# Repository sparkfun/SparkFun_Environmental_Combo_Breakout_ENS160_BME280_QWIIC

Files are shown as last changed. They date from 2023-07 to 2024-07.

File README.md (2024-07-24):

SparkFun Environmental Combo Breakout - ENS160/BME280 (Qwiic)
========================================

SparkFun Environmental Combo Breakout - ENS160/BME280 (Qwiic) (https://www.sparkfun.com/products/22858)

[*SparkFun Environmental Combo Breakout - ENS160/BME280 (Qwiic) (SEN-22858)*](https://www.sparkfun.com/products/22858)

Environmental sensor that includes the ENS160 and BME280.

Repository Contents
-------------------

* **/Documentation** - Data sheets, additional product information
* **/Hardware** - Eagle design files (.brd, .sch)
  * **/Production** - Production panel files (.brd)

Documentation
--------------
* **[ENS160 Library](https://github.com/sparkfun/SparkFun_Indoor_Air_Quality_Sensor-ENS160_Arduino_Library)** - Arduino library for the ENS160
* **[BME280 Library](https://github.com/sparkfun/SparkFun_BME280_Arduino_Library)** - Arduino library for the BME280
* **[Fritzing Part](https://github.com/sparkfun/Fritzing_Parts/blob/main/products/22858_sfe_qwiic_environmental_combo_ens160_bme280.fzpz)** - Fritzing Part for the Environmental Combo Breakout - ENS160/BME280.
* **[Hookup Guide](http://docs.sparkfun.com/SparkFun_Environmental_Combo_Breakout_ENS160_BME280_QWIIC/)** - Basic hookup guide for the Environmental Combo Breakout - ENS160/BME280.

Product Versions
----------------
* [SEN-22858](https://www.sparkfun.com/products/22858) - v1.1

Version History
---------------
* v1.0 - Initial Release

License Information
-------------------

This product is _**open source**_!

Please review the LICENSE.md file for license information.

If you have any questions or concerns on licensing, please contact technical support on our [SparkFun forums](https://forum.sparkfun.com/viewforum.php?f=152).

Distributed as-is; no warranty is given.

- Your friends at SparkFun.

_<COLLABORATION CREDIT>_

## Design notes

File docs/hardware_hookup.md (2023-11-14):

### Connecting via Qwiic

Connecting to the Qwiic Environmental Combo Breakout - ENS160/BME280 is simple. You will just need a microcontroller and a Qwiic cable. In this case, we used an ATmega328P as the microcontroller (we specifically tested the Arduino Libraries with the SparkFun RedBoard Qwiic). Insert one end of the Qwiic cable into the Qwiic Environmental Combo Breakout's Qwiic connector and the other end of the cable to your microcontroller's Qwiic connector. Then insert a USB cable into the RedBoard Qwiic to power and program.

<div style="text-align: center;">
  <table>
    <tr style="vertical-align:middle;">
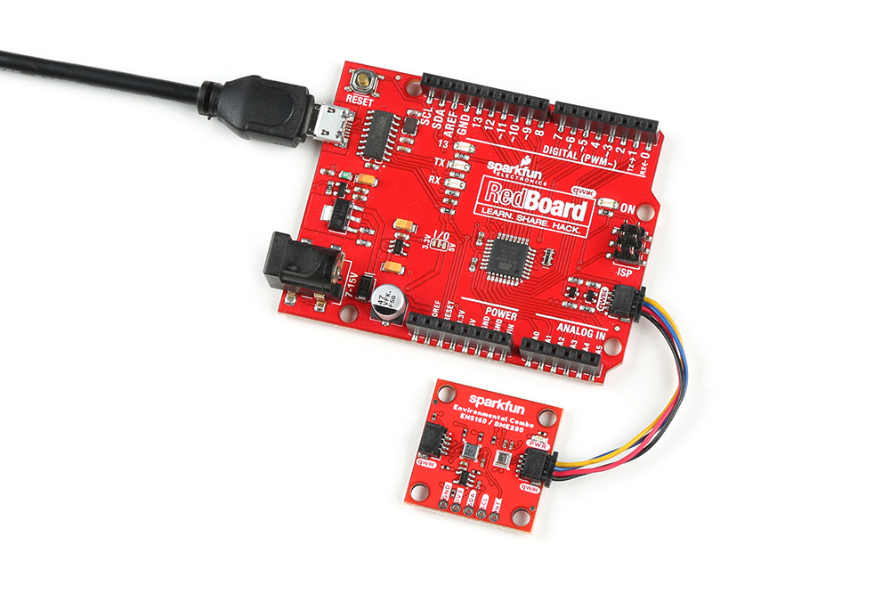
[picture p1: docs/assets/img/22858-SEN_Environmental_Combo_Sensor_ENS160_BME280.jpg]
Basic Hookup with RedBoard Qwiic, Qwiic cable, and Qwiic Environmental Combo Breakout - ENS160/BME280
     <td style="text-align: center; vertical-align: middle;"></td>
    </tr>
  </table>
</div>

### Connecting via PTH I<sup>2</sup>C and Interrupt Pins

!!! note
    For temporary connections to the PTHs, you could use IC hooks to test out the pins. However, you'll need to solder headers or wires of your choice to the board for a secure connection. You can choose between a combination of [header pins and jumper wires](https://learn.sparkfun.com/tutorials/how-to-solder-through-hole-soldering/all), or [stripping wire and soldering the wire](https://learn.sparkfun.com/tutorials/working-with-wire/all) directly to the board.

    <div class="grid cards col-4" markdown>

    -   <a href="https://learn.sparkfun.com/tutorials/how-to-solder-through-hole-soldering/all">
          <figure markdown>
            How to Solder: Through Hole Soldering
          </figure>
        </a>

        ---

        <a href="https://learn.sparkfun.com/tutorials/how-to-solder-through-hole-soldering/all">
          <b>How to Solder: Through Hole Soldering</b>
        </a>
    <!-- ----------WHITE SPACE BETWEEN GRID CARDS---------- -->

    -   <a href="https://learn.sparkfun.com/tutorials/working-with-wire/all">
          <figure markdown>
            Working with Wire
          </figure>
        </a>

        ---

        <a href="https://learn.sparkfun.com/tutorials/working-with-wire/all">
          <b>Working with Wire</b>
        </a>
    <!-- ----------WHITE SPACE BETWEEN GRID CARDS---------- -->
    </div>

For users that are connecting to the PTH I<sup>2</sup>C and interrupt pins on the edge of the board, you will need to connect the RedBoard Qwiic and sensor like the table listed below. For users that are connecting to a different microcontroller, make sure to connect to its respective pins for the I<sup>2</sup>C and interrupt pins as they may be defined differently.

<div style="text-align: center;">
    <table>
        <tr>
            <th style="text-align: center; border: solid 1px #cccccc;">RedBoard Qwiic
            <br />(I/O set to 3.3V!)
            </th>
            <th style="text-align: center; border: solid 1px #cccccc;">Environmental Combo Breakout <br />ENS160/BME280 (Qwiic)
            </th>
        </tr>
        <tr>
            <td style="text-align: center; border: solid 1px #cccccc;" bgcolor="#f2dede"><font color="#000000">3.3V</font>
            </td>
            <td style="text-align: center; border: solid 1px #cccccc;" bgcolor="#f2dede"><font color="#000000">3.3V</font>
            </td>
        </tr>
        <tr>
            <td style="text-align: center; border: solid 1px #cccccc;" bgcolor="#DDDDDD"><font color="#000000">GND</font>
            </td>
            <td style="text-align: center; border: solid 1px #cccccc;" bgcolor="#DDDDDD"><font color="#000000">GND</font>
            </td>
        </tr>
        <tr>
            <td style="text-align: center; border: solid 1px #cccccc;" bgcolor="#fff3cd"><font color="#000000">SCL (A5)</font>
            </td>
            <td style="text-align: center; border: solid 1px #cccccc;" bgcolor="#fff3cd"><font color="#000000">SCL</font>
            </td>
        </tr>
        <tr>
            <td style="text-align: center; border: solid 1px #cccccc;" bgcolor="#cce5ff"><font color="#000000">SDA (A4)</font>
            </td>
            <td style="text-align: center; border: solid 1px #cccccc;" bgcolor="#cce5ff"><font color="#000000">SDA</font>
            </td>
        </tr>    
        <tr>
            <td style="text-align: center; border: solid 1px #cccccc;" bgcolor="#cce5ff"><font color="#000000">2</font>
            </td>
            <td style="text-align: center; border: solid 1px #cccccc;" bgcolor="#cce5ff"><font color="#000000">INT</font>
            </td>
        </tr>
    </table>
</div>

Note that you will also need to also make sure that the logic levels are matched to 3.3V if you are not connecting the Qwiic connector (this connector has built-in logic level circuits on the I<up>2</sup>C data and clock lines). The default for the RedBoard Qwiic is set to 5V so you will need to cut the trace and add a solder blob between the center pad and the pad close to the 3.3V label.

<div style="text-align: center;">
  <table>
    <tr style="vertical-align:middle;">
     <td style="text-align: center; vertical-align: middle;"><a href="https://cdn.sparkfun.com/assets/learn_tutorials/8/4/4/Qwiic_Redboard_-_IO_Jumper.JPG">RedBoard Qwiic I/O Jumper Highlighted</a></td>
    </tr>
  </table>
</div>

!!! note
    For users using the [RedBoard Plus](https://www.sparkfun.com/products/18158), there is a I/O switch available as opposed to an I/O jumper. You could flip the switch toward the 3.3V side to set the logic level as well.
    <div style="text-align: center;">
      <table>
        <tr style="vertical-align:middle;">
         <td style="text-align: center; vertical-align: middle;"><a href="https://cdn.sparkfun.com/assets/learn_tutorials/1/7/5/8/18158-SparkFun_RedBoard_Plus_IO_Logic_Switch.jpg">RedBoard Plus I/O Switch Highlighted</a></td>
        </tr>
      </table>
    </div>

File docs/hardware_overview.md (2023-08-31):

The Environmental Combo Board breaks out the I<sup>2</sup>C port for the ENS160 and the BME280. The ScioSense's ENS160 is populated on the left side below the label ENS160. The independent hotplate control allows the detection of volatile organic compounds (VOCs) including ethanol, toluene, hydrogen and oxidizing gases with superior sensitivity. The ENS160 supports intelligent algorithms to process raw sensor measurements on-chip. These algorithms calculate <a href="../assets/component_documentation/ENS160-White-Paper.pdf">CO<sup>2</sup>-equivalents, TVOC, air quality indices (AQIs)</a> and perform humidity and temperature compensation, as well as baseline management, all on chip. Raw sensor measurements can be read for further customization. Bosch's BME280 is populated on the right side below the label BME280. The BME280 measures three different atmospheric properties: [ambient temperature](https://en.wikipedia.org/wiki/Atmospheric_temperature), [relative humidity](https://en.wikipedia.org/wiki/Relative_humidity), and [barometric pressure](https://en.wikipedia.org/wiki/Atmospheric_pressure). The BME280 can also calculate altitude changes, or absolute altitude if the locally reported barometric pressure is known.

<div style="text-align: center;">
  <table>
    <tr style="vertical-align:middle;">
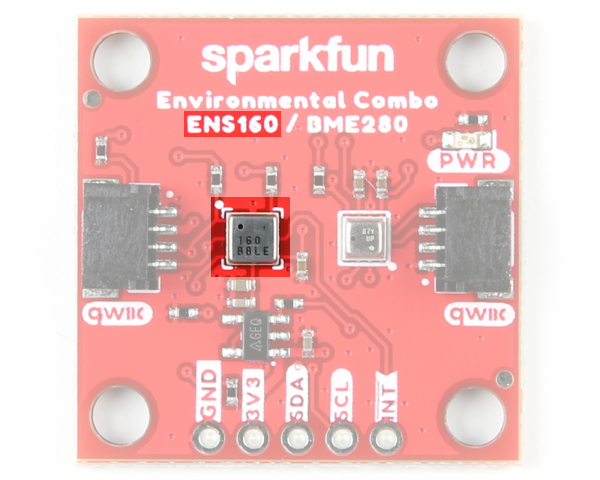
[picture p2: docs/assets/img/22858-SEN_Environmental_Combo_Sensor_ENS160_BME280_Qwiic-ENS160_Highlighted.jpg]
ENS160 Highlighted
     <td style="text-align: center; vertical-align: middle;"></td>
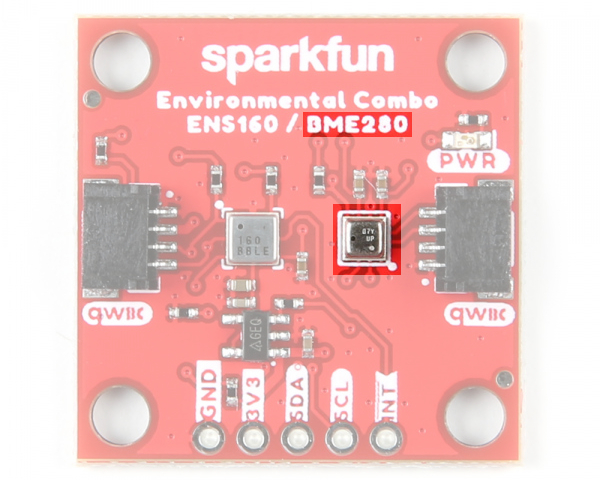
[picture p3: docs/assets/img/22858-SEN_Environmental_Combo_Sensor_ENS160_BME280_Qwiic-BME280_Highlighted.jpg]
BME280 Highlighted
     <td style="text-align: center; vertical-align: middle;"></td>
    </tr>
    <tr style="vertical-align:middle;">
     <td align="center">ENS160 Highlighted</td>
     <td align="center">BME280 Highlighted</td>
    </tr>
  </table>
</div>

Let's look over a few characteristics of the Environmental Combo Breakout - ENS160/BME280 (Qwiic) sensor so we know a bit more about how it behaves. These characteristics were taken from their respective datasheets. For more information, make sure to check out the datasheet that is linked in the Resources section.

* **ENS160**
    * I<sup>2</sup>C Addresses: **0x53 (Default)** or 0x52
    * Wide Operating Ranges
        * VDD: 1.71 1.98V
        * VDDIO: 1.71V to 3.6V
        * Temperature: -40&deg;C to +85&deg;C
        * Humidity: 5% to 95% (non-condensing)
    * IAQ standard compliance for AQI, eCO<sub>2</sub>, and TVOC
        * Air Quality Index - Umweltbundesamt (AQI-UBA)
            * Range: 1 to 5
            * Resolution: 1
        * Equivalent Carbon Dioxide (eCO<sub>2</sub>)
            * Range: 400 to 65,000 ppm
            * Resolution: 1 ppm
        * Total Volatile Organic Compound (TVOC)
            * Range: 0 to 65,000 ppb
            * Resolution: 1 ppb
    * Immunity to humidity and ozone
        * Superior output stability over the whole temperature and relative humidity operating ranges
        * Effective ozone compensation
    * Independent sensor heater control for highest VOC selectivity and outstanding background discrimination
* **BME280**
    * VDD: 1.71V to 3.6V
    * VDDIO: 1.2V to 3.6V
    * I<sup>2</sup>C Addresses: **0x77 (Default)** or 0x76
    * Temperature
        * Operating Range: -40&deg;C to 85&deg;C
        * Full accuracy to &plusmn; 0.5&deg;C from -0&deg;C to 65&deg;C
        * Resolution 0.01&deg;C
    * Humidity
        * Operating Range: 0% to 100% RH
        * Accurate to &plusmn;3% from 20% -80% RH
        * Resolution: 0.008%RH
    * Pressure
        * Operating Range: 30,000 Pa to 110,000Pa
        * Absolute Accuracy of &plusmn;100Pa
        * Relative Accuracy of &plusmn;12Pa
        * Resolution: 0.18Pa
    * Altitude Range
        * 0ft to 30,000ft (9.2km)
        * Relative accuracy of 3.3ft (1m) at sea level, 6.6 (2m) at 30,000ft

### Power

To power the board, you will need **3.3V**. You can power the board via either Qwiic connector. For users that need to solder directly to the board and do not have a Qwiic connector populated on the microcontroller, the pins are also broken out on the edge PTH. Voltage is regulated down to 1.8V for the ENS160 with the AP2127K voltage regulator. The logic levels of each sensor is 3.3V.

<div style="text-align: center;">
  <table>
    <tr style="vertical-align:middle;">
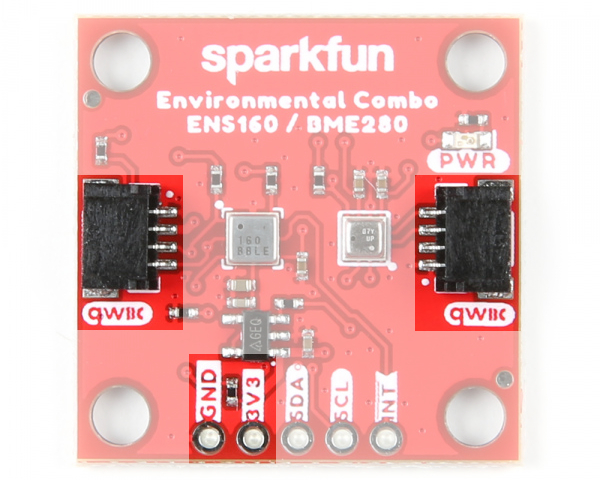
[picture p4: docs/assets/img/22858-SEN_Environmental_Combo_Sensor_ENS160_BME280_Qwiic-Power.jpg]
Power
     <td style="text-align: center; vertical-align: middle;"></td>
    </tr>
  </table>
</div>

### I<sup>2</sup>C and Qwiic Connectors

The board includes two Qwiic connectors on each side of the board. For users that need to solder directly to the board, the pins are also broken out on the edge PTH. The I<sup>2</sup>C data and clock lines are also tied to 2.2k&ohm; pull-up resistors.

<div style="text-align: center;">
  <table>
    <tr style="vertical-align:middle;">
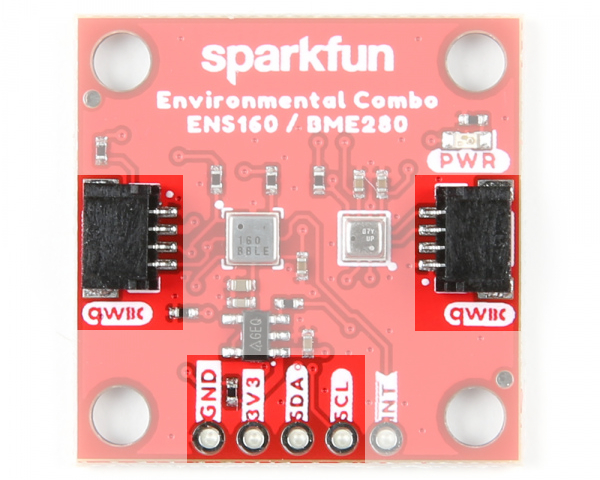
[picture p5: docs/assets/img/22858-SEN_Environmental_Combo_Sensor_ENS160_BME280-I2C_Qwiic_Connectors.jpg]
I2C Qwiic Connectors and PTH
     <td style="text-align: center; vertical-align: middle;"></td>
    </tr>
  </table>
</div>

*  The default address of the ENS160 is set to **0x53**. Its alternative address is _0x52_. The default address of the BME280 is set to **0x77**. Its alternative address is _0x76_. For more information, check out the section about the jumpers.

!!!note
    While both sensors are capable of SPI, we opted to only focus on using the sensors with I<sup>2</sup>C so only the I<sup>2</sup>C pins are broken out.

### Interrupt Pin

The interrupt pin is also broken out for the ENS160 and it is active when the pin is low.

<div style="text-align: center;">
  <table>
    <tr style="vertical-align:middle;">
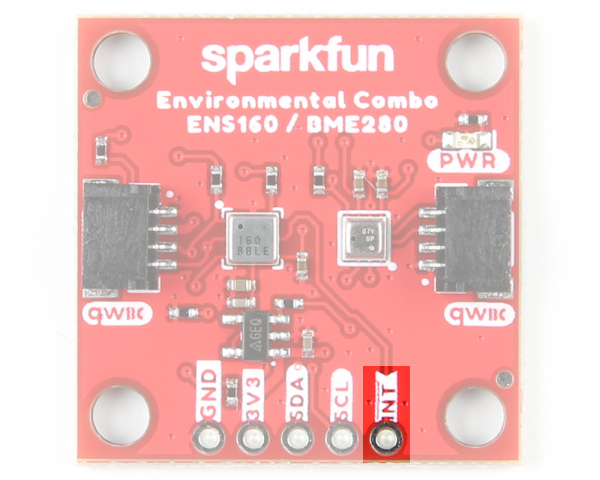
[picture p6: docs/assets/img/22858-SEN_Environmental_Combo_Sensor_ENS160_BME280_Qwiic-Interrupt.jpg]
I2C Qwiic Connectors and PTH
     <td style="text-align: center; vertical-align: middle;"></td>
    </tr>
  </table>
</div>

### LED

There is one LED on the board. The LED lights up when the board is powered with 3.3V. There is a jumper on the back if you decide to disable the LED.

<div style="text-align: center;">
  <table>
    <tr style="vertical-align:middle;">
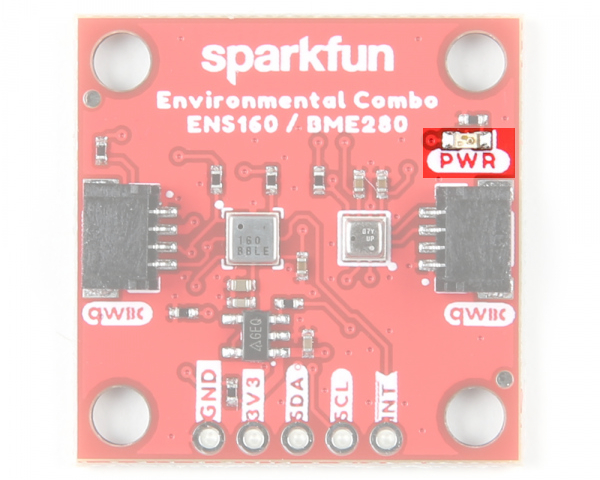
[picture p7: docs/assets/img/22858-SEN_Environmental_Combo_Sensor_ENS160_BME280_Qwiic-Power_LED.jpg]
LED
     <td style="text-align: center; vertical-align: middle;"></td>
    </tr>
  </table>
</div>

### Jumpers

There are a few jumper pads available on the bottom of the board. For more information on modifying the jumpers, check out our [tutorial on working with jumper pads and PCB traces](https://learn.sparkfun.com/tutorials/how-to-work-with-jumper-pads-and-pcb-traces).

* **LED** &mdash; The LED jumper is closed by default. Cut this trace to disable the power LED that is connected to 3.3V.
* **I2C** &mdash; The I<sup>2</sup>C jumpers are closed by default. By cutting the traces between the jumper pads, it will disconnect to the 2.2kΩ pull-up resistors for the I<sup>2</sup>C bus. Most of the time you can leave these alone unless your project requires you to [connect the pull-up resistors](https://learn.sparkfun.com/tutorials/i2c/all#i2c-at-the-hardware-level).
* **BME ADR** &mdash; This is the BME280 address select jumper. It is open by default so the address is `0x77`. By closing this jumper, the address changes to `0x76`. Make sure to also modify your code to adjust for the alternative address.
* **ENS ADR** &mdash; This is the ENS160 address select jumper. The center pad is connect to the right pad labeled as `0x53`. To use the sensor's alternative address, you will need to cut this jumper and adding a solder blob to between the center pad and the pad located on the left labeled `0x52`. If the center of the pad is left floating, the address will be undefined. Make sure to also modify your code to adjust for the alternative address.

<div style="text-align: center;">
  <table>
    <tr style="vertical-align:middle;">
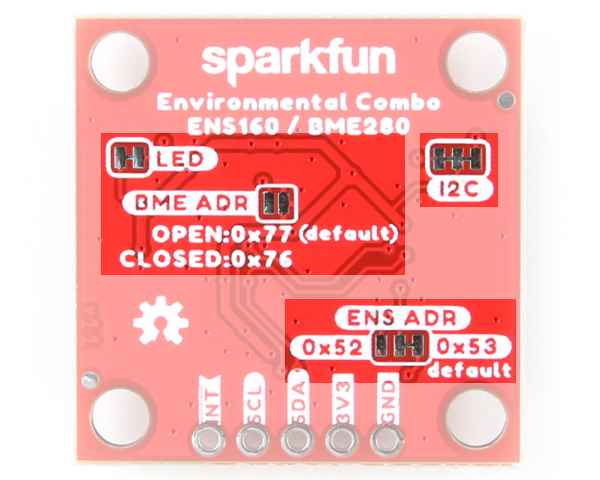
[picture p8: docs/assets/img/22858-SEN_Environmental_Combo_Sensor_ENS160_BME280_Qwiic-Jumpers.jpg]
Jumpers on the Bottom Side
     <td style="text-align: center; vertical-align: middle;"></td>
    </tr>
  </table>
</div>

### Board Dimensions

The board is 1.0" x 1.0" (25.4mm x 25.4mm). There are 4x mounting holes by each corner of the board.

<div style="text-align: center;">
  <table>
    <tr style="vertical-align:middle;">
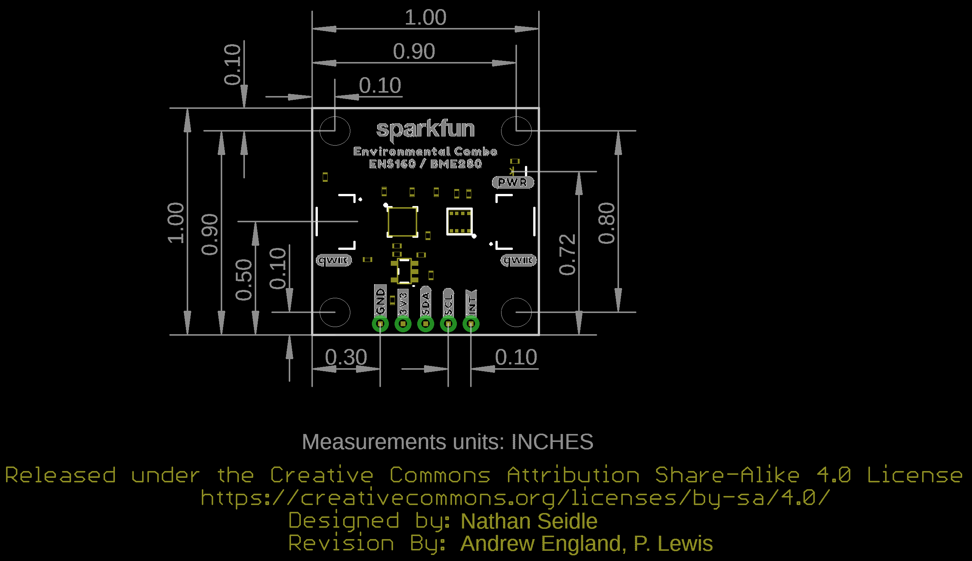
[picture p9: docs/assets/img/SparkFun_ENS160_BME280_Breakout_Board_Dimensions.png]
Board Dimesions
     <td style="text-align: center; vertical-align: middle;"></td>
    </tr>
  </table>
</div>

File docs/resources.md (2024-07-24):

Now that you've successfully got your SparkFun Environmental Combo Breakout - ENS160/BME280 (Qwiic) up and running, it's time to incorporate it into your own project! For more information, check out the resources below:

* [Schematic (PDF)](../assets/board_files/SparkFun_ENS160_BME280_Breakout_Schematic_V11.pdf)
* [Eagle Files (ZIP)](../assets/board_files/SparkFun_ENS160_BME280_Breakout_v11.zip)
* [Board Dimensions (PNG)](../assets/img/SparkFun_ENS160_BME280_Breakout_Board_Dimensions.png)
* Datasheet (PDF)
    * [ENS160](../assets/component_documentation/SC-001224-DS-7-ENS160-Datasheet.pdf)
    * [BME280](../assets/component_documentation/bst-bme280-ds002.pdf)
* [ENS160 White Paper (PDF)](..\assets\component_documentation\ENS160-White-Paper.pdf)
* Arduino Libraries
    * [ENS160](https://github.com/sparkfun/SparkFun_Indoor_Air_Quality_Sensor-ENS160_Arduino_Library)
    * [BME280](https://github.com/sparkfun/SparkFun_BME280_Arduino_Library)
* [Fritzing Part](https://github.com/sparkfun/Fritzing_Parts/blob/main/products/22858_sfe_qwiic_environmental_combo_ens160_bme280.fzpz)
* [SFE Product Showcase](https://youtu.be/78wqEFfHv_c?si=ASorMzOgZIkLuGjM)

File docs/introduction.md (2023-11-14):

The [SparkFun Qwiic Environmental Combo Breakout - ENS160/BME280](https://www.sparkfun.com/products/22858) takes care of all your atmospheric-quality sensing needs with the popular ENS160 and BME280 ICs. This unique breakout provides a variety of environmental data, including AQI, TVOCs, equivalent CO<sub>2</sub> (or eCO<sub>2</sub>) levels, barometric pressure, humidity, and temperature.

<center>
<div class="grid cards" style="width:500px;" markdown>

-   <a href="https://www.sparkfun.com/products/22858">
      <figure markdown>
        SparkFun VR IMU Breakout - BNO086 (Qwiic)
      </figure>
    </a>

    ---

    <a href="https://www.sparkfun.com/products/22858">
      <b>SparkFun Environmental Combo Breakout - ENS160/BME280 (Qwiic)</b>
      <br />
      SEN-22858
      <br />
      <center>[Purchase from SparkFun :fontawesome-solid-cart-plus:](https://www.sparkfun.com/products/22858){ .md-button .md-button--primary }</center>
    </a>

</div>
</center>

<div style="text-align: center;">
  <iframe width="560" height="315" src="https://www.youtube.com/embed/78wqEFfHv_c?si=gWOqpgGb7HURjOYh" title="YouTube video player" frameborder="0" allow="accelerometer; autoplay; clipboard-write; encrypted-media; gyroscope; picture-in-picture; web-share" allowfullscreen></iframe>
</div>

In this tutorial, we'll go over the hardware and how to hookup the sensor to an Arduino. We will also go over the basic Arduino examples to get started!

### Required Materials

To follow along with this tutorial, you will need the following materials. You may not need everything though depending on what you have. Add it to your cart, read through the guide, and adjust the cart as necessary.

* 1x [SparkFun RedBoard Qwiic [DEV-15123]](https://www.sparkfun.com/products/15123)
* 1x [USB micro-B Cable - 6 Foot [CAB-10215]](https://www.sparkfun.com/products/10215)
* 1x [SparkFun Environmental Combo Breakout - ENS160/BME280 (Qwiic) [SEN-22858]](https://www.sparkfun.com/products/22858)
* 1x Qwiic Cable
    * [Flexible Qwiic Cable - 50mm [PRT-17260]](https://www.sparkfun.com/products/17260), for short distances
    * [Flexible Qwiic Cable - 500mm [PRT-17257]](https://www.sparkfun.com/products/17257), for those that need to wire the board farther away from your microcontroller

<div class="grid cards col-4" markdown>

-   <a href="https://www.sparkfun.com/products/15123">
      <figure markdown>
        SparkFun RedBoard Qwiic
      </figure>
    </a>

    ---

    <a href="https://www.sparkfun.com/products/15123">
      <b>SparkFun RedBoard Qwiic</b>
      <br />
      DEV-15123
    </a>
<!-- ----------WHITE SPACE BETWEEN PRODUCTS---------- -->
-   <a href="https://www.sparkfun.com/products/10215">
      <figure markdown>
        USB micro-B Cable - 6 Foot
      </figure>
    </a>

    ---

    <a href="https://www.sparkfun.com/products/10215">
      <b>USB micro-B Cable - 6 Foot</b>
      <br />
      CAB-15092
    </a>
<!-- ----------WHITE SPACE BETWEEN PRODUCTS---------- -->
-   <a href="https://www.sparkfun.com/products/22858">
      <figure markdown>
        SparkFun Environmental Combo Breakout - ENS160/BME280 (Qwiic)
      </figure>
    </a>

    ---

    <a href="https://www.sparkfun.com/products/22858">
      <b>SparkFun Environmental Combo Breakout - ENS160/BME280 (Qwiic)</b>
      <br />
      SEN-22858
    </a>
<!-- ----------WHITE SPACE BETWEEN PRODUCTS---------- -->
-   <a href="https://www.sparkfun.com/products/17260">
      <figure markdown>
        Flexible Qwiic Cable - 50mm
      </figure>
    </a>

    ---

    <a href="https://www.sparkfun.com/products/17260">
      <b>Flexible Qwiic Cable - 50mm</b>
      <br>
      PRT-17260
    </a>
<!-- ----------WHITE SPACE BETWEEN PRODUCTS---------- -->

</div>

### Tools (Optional)

For those that need to solder to the PTHs, you will need to solder two wires between your microcontroller and the breakout board. This requires some assembly and soldering. You may already have a few of these items but if not, the tools and hardware below help with that assembly.

* [Hook-Up Wire - Assortment (Stranded, 22 AWG) [PRT-11375]](https://www.sparkfun.com/products/11375)
* [Wire Stripper - 20-30 AWG Solid (22-32 AWG Stranded) [TOL-22263]](https://www.sparkfun.com/products/22263)
* [Soldering Iron [TOL-14456]](https://www.sparkfun.com/products/14456)
* [Solder Lead Free - 15-gram Tube [TOL-9163]](https://www.sparkfun.com/products/9163)

<div class="grid cards col-4" markdown>

-   <a href="https://www.sparkfun.com/products/11375">
      <figure markdown>
        Hook-Up Wire - Assortment (Stranded, 22 AWG)
      </figure>
    </a>

    ---

    <a href="https://www.sparkfun.com/products/11375">
      <b>Hook-Up Wire - Assortment (Stranded, 22 AWG)</b>
      <br />
      PRT-11375
    </a>
<!-- ----------WHITE SPACE BETWEEN PRODUCTS---------- -->
-   <a href="https://www.sparkfun.com/products/22263">
      <figure markdown>
        Wire Stripper - 20-30 AWG Solid (22-32 AWG Stranded)
      </figure>
    </a>

    ---

    <a href="https://www.sparkfun.com/products/22263">
      <b>Wire Stripper - 20-30 AWG Solid (22-32 AWG Stranded)</b>
      <br />
      TOL-22263
    </a>
<!-- ----------WHITE SPACE BETWEEN PRODUCTS---------- -->
-   <a href="https://www.sparkfun.com/products/14456">
      <figure markdown>
        Soldering Iron - 60W (Adjustable Temperature)
      </figure>
    </a>

    ---

    <a href="https://www.sparkfun.com/products/14456">
      <b>Soldering Iron - 60W (Adjustable Temperature)</b>
      <br />
      TOL-14456
    </a>
<!-- ----------WHITE SPACE BETWEEN PRODUCTS---------- -->
-   <a href="https://www.sparkfun.com/products/9163">
      <figure markdown>
        Solder Lead Free - 15-gram Tube
      </figure>
    </a>

    ---

    <a href="https://www.sparkfun.com/products/9163">
      <b>Solder Lead Free - 15-gram Tube</b>
      <br>
      TOL-09163
    </a>
<!-- ----------WHITE SPACE BETWEEN PRODUCTS---------- -->
</div>

### Suggested Reading

If you aren't familiar with the Qwiic Connection System, we recommend reading [here for an overview](https://www.sparkfun.com/qwiic).

<div style="text-align: center">
  <table style="border-style:none">
    <tr>
     <td style="text-align: center; vertical-align: middle;">
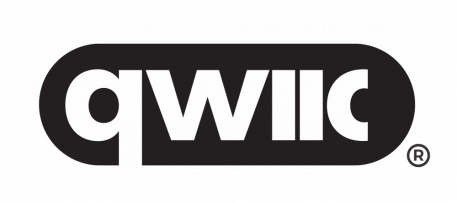
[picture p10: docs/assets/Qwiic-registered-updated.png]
Qwiic Connection System Click to learn more about the Qwiic Connection System!
     <div style="text-align: center">
     </div>
    </td>
    </tr>
    <tr>
      <td style="text-align: center; vertical-align: middle;"><div style="text-align: center"><i><a href="https://www.sparkfun.com/qwiic">Qwiic Connection System</a></i></div></td>
    </tr>
  </table>
</div>

If you aren’t familiar with the following concepts, we also recommend checking out a few of these tutorials before continuing.

<div class="grid cards col-4" markdown>

-   <a href="https://learn.sparkfun.com/tutorials/redboard-qwiic-hookup-guide">
      <figure markdown>
        RedBoard Qwiic Hookup Guide
      </figure>
    </a>

    ---

    <a href="https://learn.sparkfun.com/tutorials/redboard-qwiic-hookup-guide">
      <b>RedBoard Qwiic Hookup Guide</b>
    </a>
<!-- ----------WHITE SPACE BETWEEN GRID CARDS---------- -->
-   <a href="https://learn.sparkfun.com/tutorials/sparkfun-indoor-air-quality-sensor---ens160-qwiic-hookup-guide">
      <figure markdown>
        SparkFun Indoor Air Quality Sensor - ENS160 (Qwiic) Hookup Guide
      </figure>
    </a>

    ---

    <a href="https://learn.sparkfun.com/tutorials/sparkfun-indoor-air-quality-sensor---ens160-qwiic-hookup-guide">
      <b>SparkFun Indoor Air Quality Sensor - ENS160 (Qwiic) Hookup Guide</b>
    </a>
<!-- ----------WHITE SPACE BETWEEN GRID CARDS---------- -->
-   <a href="https://learn.sparkfun.com/tutorials/qwiic-atmospheric-sensor-bme280-hookup-guide/">
      <figure markdown>
        Qwiic Atmospheric Sensor (BME280) Hookup Guide
      </figure>
    </a>

    ---

    <a href="https://learn.sparkfun.com/tutorials/qwiic-atmospheric-sensor-bme280-hookup-guide/">
      <b>Qwiic Atmospheric Sensor (BME280) Hookup Guide</b>
    </a>
<!-- ----------WHITE SPACE BETWEEN GRID CARDS---------- -->
-   <a href="https://learn.sparkfun.com/tutorials/i2c">
      <figure markdown>
        I2C
      </figure>
    </a>

    ---

    <a href="https://learn.sparkfun.com/tutorials/i2c">
      <b>I2C</b>
    </a>
<!-- ----------WHITE SPACE BETWEEN GRID CARDS---------- -->
-   <a href="https://learn.sparkfun.com/tutorials/terminal-basics">
      <figure markdown>
        Serial Terminal Basics
      </figure>
    </a>

    ---

    <a href="https://learn.sparkfun.com/tutorials/terminal-basics">
      <b>Serial Terminal Basics</b>
    </a>
<!-- ----------WHITE SPACE BETWEEN GRID CARDS---------- -->
-   <a href="https://learn.sparkfun.com/tutorials/installing-an-arduino-library">
      <figure markdown>
        Installing an Arduino Library
      </figure>
    </a>

    ---

    <a href="https://learn.sparkfun.com/tutorials/installing-an-arduino-library">
      <b>Installing an Arduino Library</b>
    </a>
<!-- ----------WHITE SPACE BETWEEN GRID CARDS---------- -->
</div>

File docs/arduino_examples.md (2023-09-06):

Now that we have our library installed, we can get started playing around with our examples for each sensor. For the scope of this tutorial, we will combine the basic examples to output the values to a Serial Monitor. Then we will use the BME280 to compensate for the temperature and relative humidity. From there we will be able to build our own custom code to integrate the sensor into a project.

### Example 1: ENS160 and BME280 Combined Examples

Below is the combined example to read ENS160 and BME280. Copy and paste the code below in your Arduino IDE.

??? code "Example 1: ENS160 and BME280 Combined Examples"
    === "Ex1_Combined_Basic_Example_ENS160_BME280.ino"
        ``` c++ linenums="1"
        --8<-- "https://raw.githubusercontent.com/sparkfun/SparkFun_Environmental_Combo_Breakout_ENS160_BME280_QWIIC/main/Firmware/Ex1_Combined_Basic_Example_ENS160_BME280/Ex1_Combi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"
        ```

Select your board in the Tools menu (in our case **Arduino Uno**) and the correct Port it enumerated on and click "Upload". After uploading the code, open the [Serial Monitor](https://learn.sparkfun.com/tutorials/terminal-basics) or terminal emulator of your choice with the baud rate set to **115200**.

<div style="text-align: center;">
  <table>
    <tr style="vertical-align:middle;">
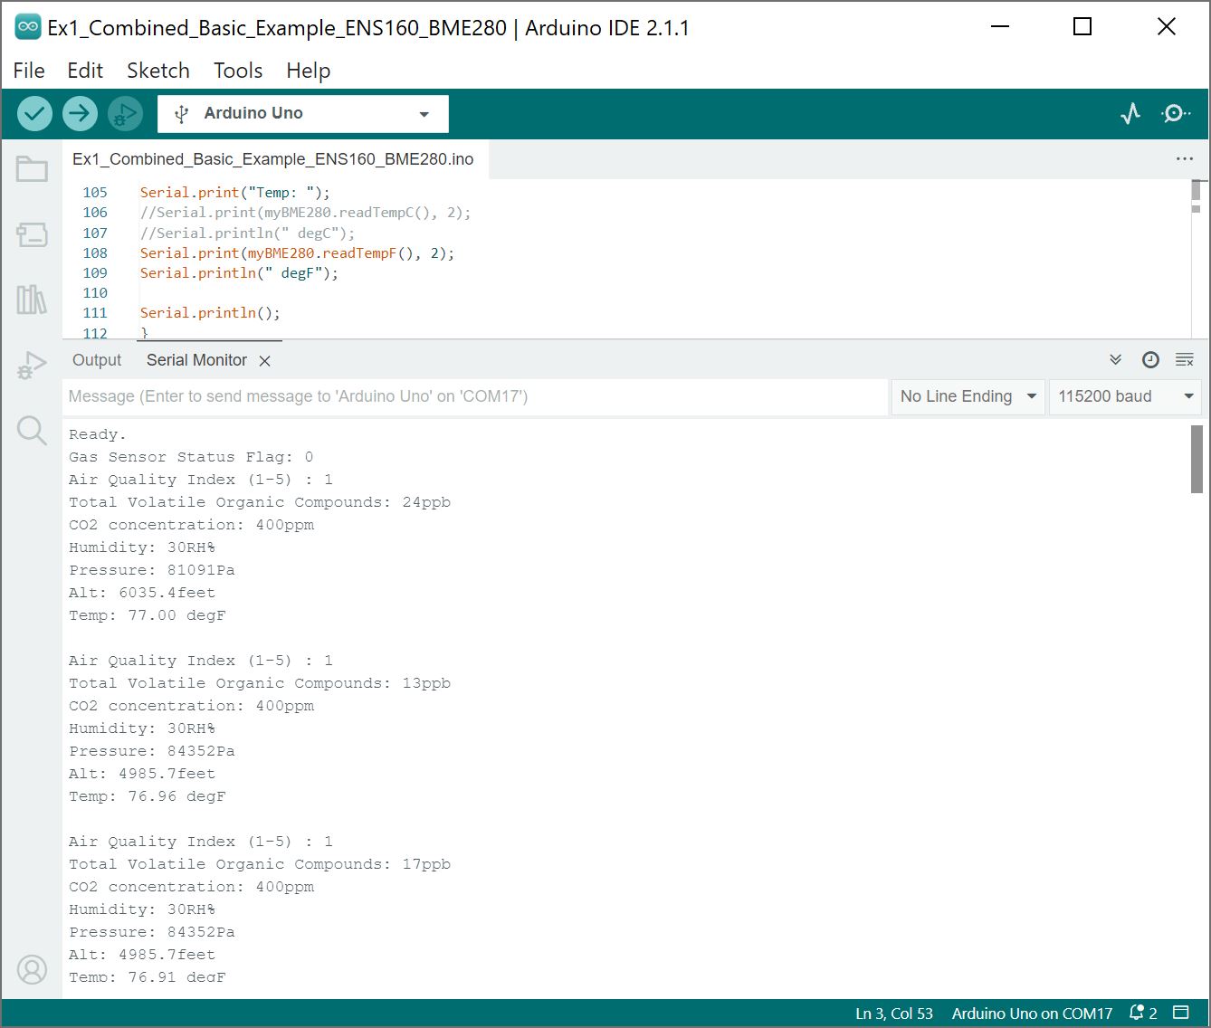
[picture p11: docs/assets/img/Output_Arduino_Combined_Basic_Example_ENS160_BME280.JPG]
Combined Output Arduino ENS160 and BME280
     <td style="text-align: center; vertical-align: middle;"></td>
    </tr>
  </table>
</div>

!!! note
    Note that the ENS160 needs some time to calculate values as stated in the datasheet on page 15 and 16 before the measurements are reasonable. Try moving the `ensStatus` into the loop to monitor the reliability of the ENS160's output.

    #### Initial Start-Up

    <quote>Initial Start-Up is the time the ENS160 needs to exhibit reasonable air quality readings after its first ever power-on.

    The ENS160 sensor raw resistance signals and sensitivities will change upon first power-on. The change in resistance is greatest in the first 48 hours of operation. Therefore, the ENS160 employs a start-up algorithm, allowing eCO2, TVOC and AQI output signals to be used from first power-on after 1 hour of operation.</quote>

    #### Initial Warm-Up

    <quote>Further to “Initial Start-up” the conditioning or “Warm-up” period is the time required to achieve adequate sensor stability before measuring VOCs after idle periods or power-off. Typically, the ENS160 requires 3 minutes of warm-up until reasonable air quality readings can be expected.</quote>

### Example 2: Combined Basic Example ENS160/BME280 in CSV Format

Below is the same combined code but formatted for CSV. Copy and paste the code below in your Arduino IDE.

??? code "Example 2: Combined Basic Example ENS160/BME280 in CSV Format"
    === "Ex2_Combined_Basic_Example_ENS160_BME280_CSV.ino"
        ``` c++ linenums="1"
        --8<-- "https://raw.githubusercontent.com/sparkfun/SparkFun_Environmental_Combo_Breakout_ENS160_BME280_QWIIC/main/Firmware/Ex2_Combined_Basic_Example_ENS160_BME280_CSV/Ex2_C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"
        ```

Select your board in the Tools menu (in our case **Arduino Uno**) and the correct Port it enumerated on and click "Upload". After uploading the code, open the [Serial Monitor](https://learn.sparkfun.com/tutorials/terminal-basics) or terminal emulator of your choice with the baud rate set to **115200**.

<div style="text-align: center;">
  <table>
    <tr style="vertical-align:middle;">
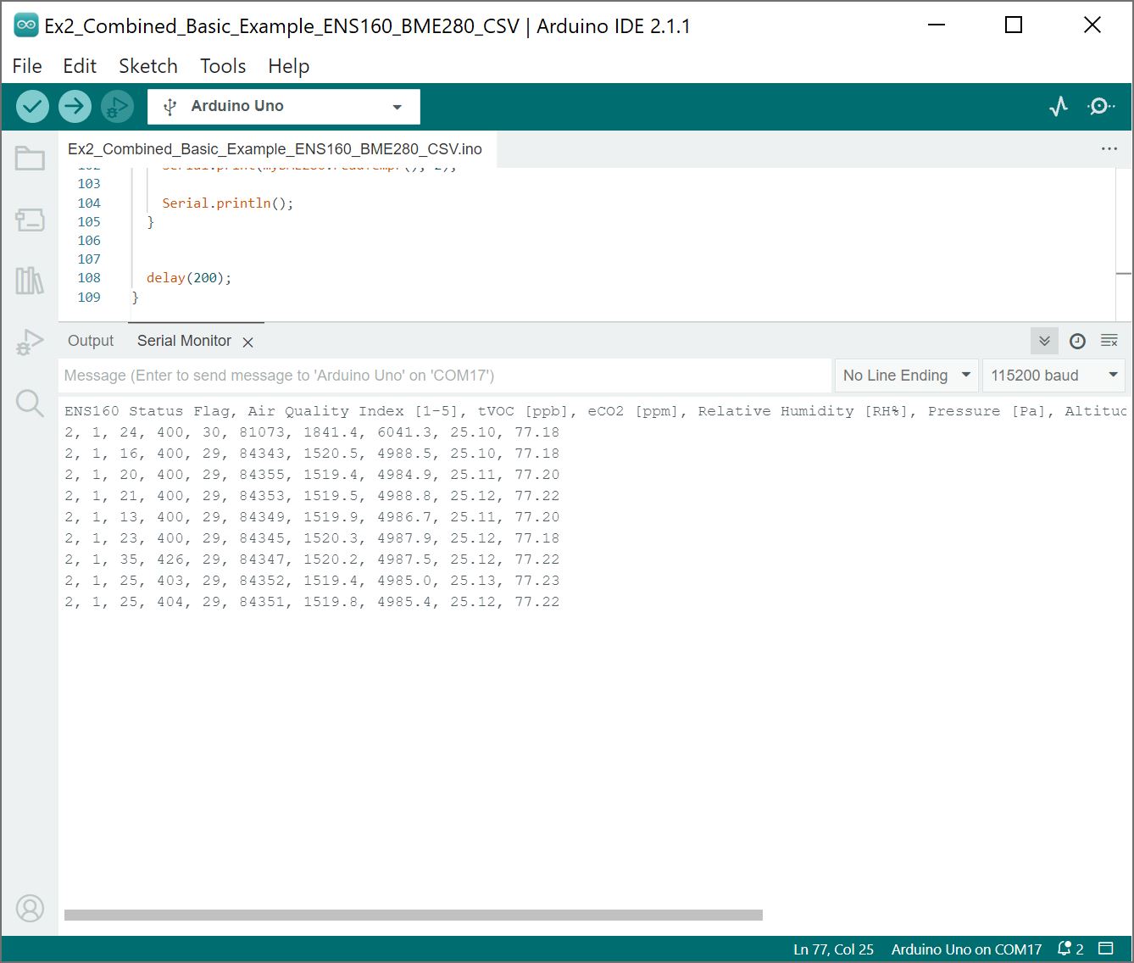
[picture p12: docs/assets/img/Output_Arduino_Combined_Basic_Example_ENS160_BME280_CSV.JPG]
Combined Output Arduino ENS160 and BME280 in CSV
     <td style="text-align: center; vertical-align: middle;"></td>
    </tr>
  </table>
</div>

### Example 3: BME280 Temperature and Relative Humidity Compensation

!!! note
    This example is actually in the ENS160 Arduino Library! [It is listed as example 4](https://github.com/sparkfun/SparkFun_Indoor_Air_Quality_Sensor-ENS160_Arduino_Library/blob/main/examples/example4_BME280_temp_rh_compensation/example4_BME280_temp_rh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) even though in this tutorial we are referring to it as "example 3."

The example code below uses the BME280 for temperature and relative humidity compensation when reading values from the ENS160. Copy and paste the code below in your Arduino IDE.

??? code "Example 3: BME280 Temperature and Relative Humidity Compensation"
    === "example4_BME280_temp_rh_compensation.ino"
        ``` c++ linenums="1"
        --8<-- "https://raw.githubusercontent.com/sparkfun/SparkFun_Indoor_Air_Quality_Sensor-ENS160_Arduino_Library/main/examples/example4_BME280_temp_rh_compensation/example4_BME2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"
        ```

Select your board in the Tools menu (in our case **Arduino Uno**) and the correct Port it enumerated on and click "Upload". After uploading the code, open the [Serial Monitor](https://learn.sparkfun.com/tutorials/terminal-basics) or terminal emulator of your choice with the baud rate set to **115200**.

<div style="text-align: center;">
  <table>
    <tr style="vertical-align:middle;">
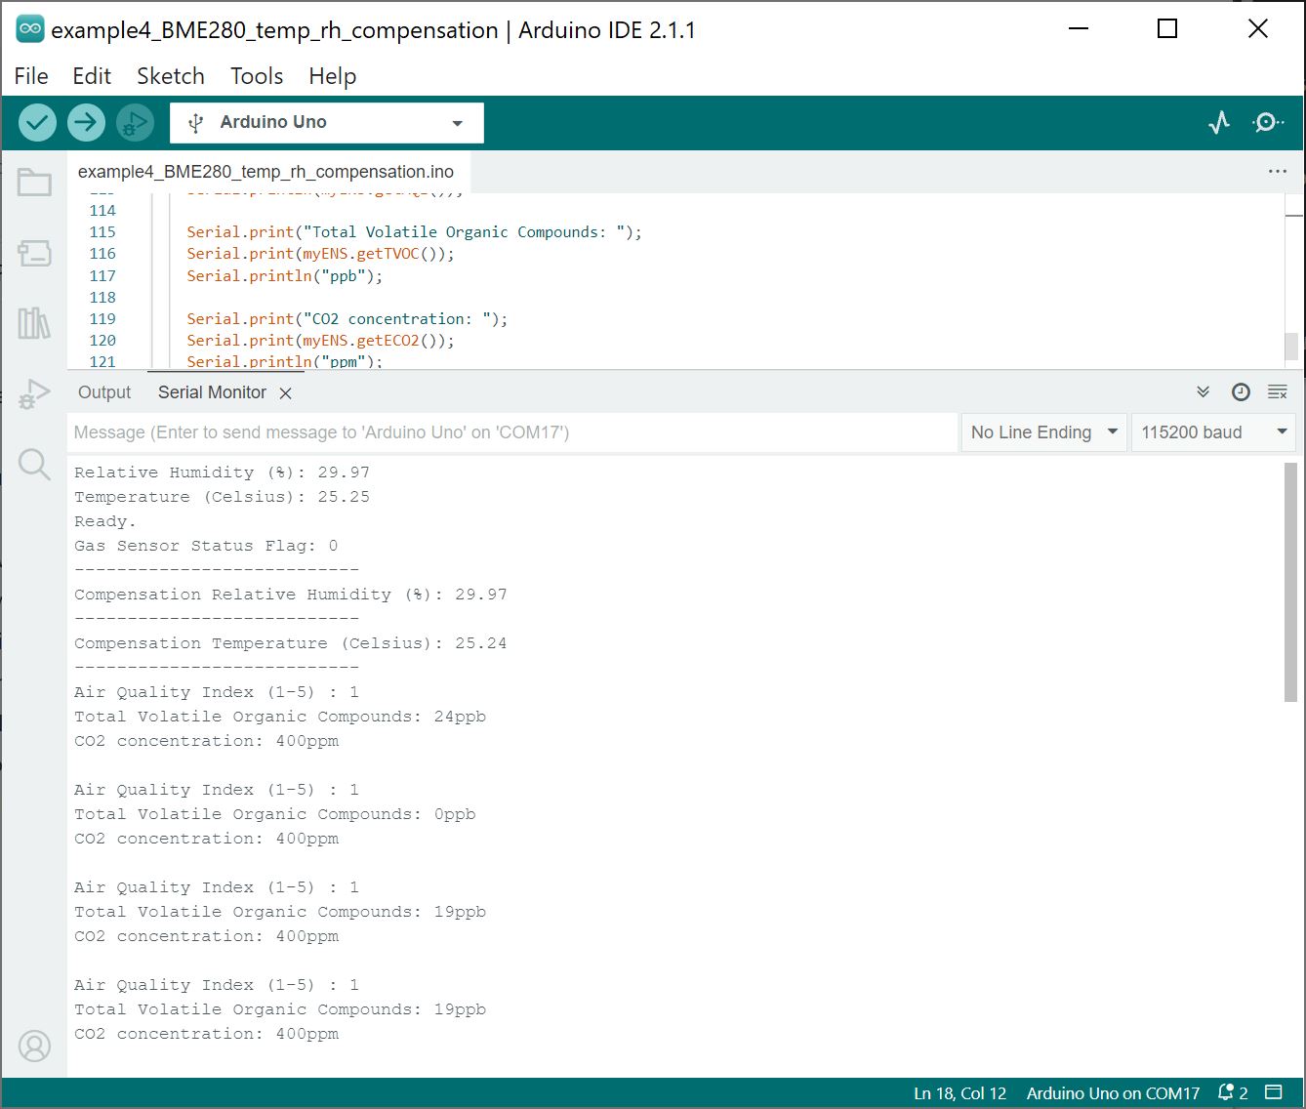
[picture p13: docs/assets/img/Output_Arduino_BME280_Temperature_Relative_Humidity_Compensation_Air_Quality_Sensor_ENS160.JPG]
Output Arduino BME280 Temperature and Humidity Compensated Air Quality Sensor ENS160
     <td style="text-align: center; vertical-align: middle;"></td>
    </tr>
  </table>
</div>

### More Examples!!!

Make sure to check the Arduino Libraries that you installed on your computer for more examples with the ENS160 and BME280! Remember, the SPI port is not broken out on the Environmental Combo Breakout - ENS160/BME280 so those examples will not apply for this specific board.

<div style="text-align: center">
    <a href="https://github.com/sparkfun/SparkFun_Indoor_Air_Quality_Sensor-ENS160_Arduino_Library/tree/main/examples" class="md-button">GitHub SparkFun > SparkFun_Indoor_Air_Quality_Sensor-ENS160_Arduino_Library > Examples</a>
    <br /><br />
    <a href="https://github.com/sparkfun/SparkFun_BME280_Arduino_Library/tree/master/examples" class="md-button md-button">GitHub SparkFun > SparkFun_BME280_Arduino_Library > Examples</a></div>

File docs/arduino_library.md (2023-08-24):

!!! arduino

    ### Arduino IDE

    This example assumes you are using the latest version of the Arduino IDE on your desktop. If this is your first time using Arduino IDE and an library, please review the following tutorials.

    - [Installing the Arduino IDE](https://learn.sparkfun.com/tutorials/installing-arduino-ide)
    - [Installing an Arduino Library](https://learn.sparkfun.com/tutorials/installing-an-arduino-library)

    ### USB-to-Serial Drivers

    If you've never connected an CH340 device to your computer before, you may need to install drivers for the USB-to-serial converter. Check out our section on "[How to Install CH340 Drivers](https://learn.sparkfun.com/tutorials/sparkfun-serial-basic-ch340c-hookup-guide#drivers-if-you-need-them)" for help with the installation.

### ENS160

SparkFun has written a library to work with the SparkFun Indoor Air Quality Sensor - ENS160 (Qwiic). This library can be used by extension with the **Qwiic Environmental Combo Breakout - ENS160/BME280**. You can obtain this library through the Arduino Library Manager by searching for "**ENS160**". Find the one written by SparkFun Electronics and install the latest version. Users who prefer to manually install the library can get it from the  [GitHub Repository](https://github.com/sparkfun/SparkFun_Indoor_Air_Quality_Sensor-ENS160_Arduino_Library)or download the .ZIP by clicking the button below:

<div style="text-align: center"><a href="https://github.com/sparkfun/SparkFun_Indoor_Air_Quality_Sensor-ENS160_Arduino_Library/archive/refs/heads/main.zip" class="md-button">SparkFun Indoor Air Quality Sensor - ENS160 Arduino Library (ZIP)</a></div>

### BME280

SparkFun has written a library to work with the SparkFun Qwiic Atmospheric Sensor - BME280 (Qwiic). This library can be used by extension with the **Qwiic Environmental Combo Breakout - ENS160/BME280**. You can obtain this library through the Arduino Library Manager by searching for "**BME280**". Find the one written by SparkFun Electronics and install the latest version. Users who prefer to manually install the library can get it from the  [GitHub Repository](https://github.com/sparkfun/SparkFun_BME280_Arduino_Library) or download the .ZIP by clicking the button below:

<div style="text-align: center"><a href="https://github.com/sparkfun/SparkFun_BME280_Arduino_Library/archive/refs/heads/master.zip" class="md-button">SparkFun BME280 Arduino Library (ZIP)</a></div>

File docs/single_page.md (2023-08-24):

---
hide:
  - navigation
  - toc
icon: fontawesome/solid/scroll
---

# Introduction
--8<-- "./docs/introduction.md"

# Hardware Overview
--8<-- "./docs/hardware_overview.md"

# Hardware Hookup
--8<-- "./docs/hardware_hookup.md"

# Installing the Arduino Library
--8<-- "./docs/arduino_library.md"

# Arduino Examples
--8<-- "./docs/arduino_examples.md"

# Troubleshooting
--8<-- "./docs/troubleshooting.md"

# Resources
--8<-- "./docs/resources.md"

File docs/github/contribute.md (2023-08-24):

# Contribute: Help Fix our Mistake!
Spot something wrong? Feel free to contribute our open-source design and documentation. 

## Improve our Documentation
All of this documentation can be modified by you! Please help us make it better.

* These pages are contained in the [`docs` folder of the SparkFun Environmental Combo Breakout ENS160/BME280 (Qwiic) repository](https://github.com/sparkfun/SparkFun_Environmental_Combo_Breakout_ENS160_BME280_QWIIC/tree/main/docs).

### Submit a Correction
1. Fork this repo
2. Add your corrections or improvements to the markdown file
3. File a pull request with your changes, and enjoy making the ~~words~~ ~~worlds~~ world a better place.
    * Once received, the documentation specialist will automatically be notified.
    * We will review your suggested improvements to make sure they are correct and fit within our documentation standards.

## Improve our Hardware Design
All of our designs are open-source! Please help us make it better.

* Our board design files are contained in the [`Hardware` folder of the SparkFun Environmental Combo Breakout ENS160/BME280 (Qwiic) repository](https://github.com/sparkfun/SparkFun_Environmental_Combo_Breakout_ENS160_BME280_QWIIC/tree/main/Hardware).

### Submit a Design Improvement
1. Fork this repo
2. Add your design improvements
3. File a pull request with your changes, and enjoy making the ~~words~~ ~~worlds~~ world a better place.
    * Once received, the engineer in charge of the original design will automatically be notified.
    * We will review your suggested improvements, if they are within our board design standards and meet our product design requirements, we will flag these changes for our next board revision. *(Please note, that even if your suggestion is accepted, these changes may not be immediate. We may have to cycle through our current product inventory first.)*

## Contributors
Let's provided some recognition to the contributors for this project!

GitHub Contributors Image
<br>


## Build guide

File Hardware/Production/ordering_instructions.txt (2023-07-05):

panel size, 169x117mm
PCB thickness, 1.6mm
number of layers, 2
soldermask color, Red
silkscreen color, White
oz copper, 1oz
finish, HASL lead free
stencils, top
pcs per panel, 24
min trace width, 0.2032mm / 0.0080in
min drill size, 0.3048mm / 0.0120in

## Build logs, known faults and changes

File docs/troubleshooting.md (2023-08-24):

### General Troubleshooting Help

!!! note
    <span class="glyphicon glyphicon-question-sign" aria-hidden="true"></span>
        <strong> Not working as expected and need help? </strong> <br /><br />

    If you need technical assistance and more information on a product that is not working as you expected, we recommend heading on over to the <a href="https://www.sparkfun.com/technical_assistance">SparkFun Technical Assistance</a> page for some initial troubleshooting. <br /><br />

    <div style="text-align: center"><a href="https://www.sparkfun.com/technical_assistance" target="sfe_technical_assistance" class="md-button">SparkFun Technical Assistance Page</a></div>

    If you don't find what you need there, the <a href="https://forum.sparkfun.com/">SparkFun Forums</a> are a great place to find and ask for help. If this is your first visit, you'll need to <a href="https://forum.sparkfun.com/ucp.php?mode=register">create a Forum Account</a> to search product forums and post questions.<br /><br />

    <div style="text-align: center"><a href="https://forum.sparkfun.com/ucp.php?mode=register" class="md-button">Create New Forum Account</a>&nbsp;&nbsp;&nbsp;<a href="https://forum.sparkfun.com/viewforum.php?f=180" class="md-button md-button--primary">Log Into SparkFun Forums</a></div>

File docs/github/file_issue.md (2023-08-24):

# Did we make a mistake?

Spot something wrong? Please let us know. 

!!! attention
    This is not where customers should seek assistance on a product. If you require technical assistance or have questions about a product that is not working as expected, please head over to the [SparkFun Technical Assistance](https://www.sparkfun.com/technical_assistance) page for some initial troubleshooting.
    <center>
    [SparkFun Technical Assistance Page](https://www.sparkfun.com/technical_assistance){ .md-button .md-button--primary }
    </center>

    If you can't find what you need there, you'll need a [Forum Account](https://forum.sparkfun.com/ucp.php?mode=register) to search product forums and post questions.

## Discrepancies in the Documentation

All of this documentation can be modified by you! Please help us make it better.

* The documentation files for these pages are contained in the [`docs` folder of the SparkFun Environmental Combo Breakout ENS160/BME280 (Qwiic) repository](https://github.com/sparkfun/SparkFun_Environmental_Combo_Breakout_ENS160_BME280_QWIIC/tree/main/docs).

### Spot something wrong?
If a section of the documentation is incorrect, please [open an issue](https://github.com/sparkfun/SparkFun_Environmental_Combo_Breakout_ENS160_BME280_QWIIC/issues) and let us know.

### Do you have a suggested correction?
1. With a GitHub account, fork this repo
2. Add your correction(s) or improvement(s) to the markdown file(s)
3. File a pull request with your changes, and enjoy making the ~~words~~ ~~worlds~~ world a better place.
    * Once received, the documentation specialist will automatically be notified.
    * We will review your suggested improvement(s) to make sure they are correct and fit within our documentation standards.

## Problems in the Hardware Design

All of our designs are open-source! Please help us make it better.

* Our board design files are contained in the [`Hardware` folder of the SparkFun Environmental Combo Breakout ENS160/BME280 (Qwiic) repository](https://github.com/sparkfun/SparkFun_Environmental_Combo_Breakout_ENS160_BME280_QWIIC/tree/main/Hardware).

### Does something not make sense?
If part of the design is confusing, please [open an issue](https://github.com/sparkfun/SparkFun_Environmental_Combo_Breakout_ENS160_BME280_QWIIC/issues) and let us know.

### Did we forget to include an important function of the board?
* Please keep in mind that we may intentionally exclude certain functions of the board to meet our product design requirements. *(For example, our Qwiic Micro boards are intended to fit on a small board layout and only use I<sup>2</sup>C communication; therefore, we may not have the SPI and interrupt pins available for users.)*
* If part of the board's functionality is missing, please [open an issue](https://github.com/sparkfun/SparkFun_Environmental_Combo_Breakout_ENS160_BME280_QWIIC/issues) and file a feature request.

### Do you wish to contribute directly to improving the board design?
1. With a GitHub account, Fork this repo
2. Add your design improvement(s)
3. File a pull request with your changes, and enjoy making the ~~words~~ ~~worlds~~ world a better place.
    * Once received, the engineer in charge of the original design will automatically be notified.
    * We will review your suggested improvement(s), if they are within our board design standards and meet our product design requirements, we will flag these changes for our next board revision. *(Please note, that even if your suggestion is accepted, these changes may not be immediate. We may have to cycle through our current product inventory first.)*

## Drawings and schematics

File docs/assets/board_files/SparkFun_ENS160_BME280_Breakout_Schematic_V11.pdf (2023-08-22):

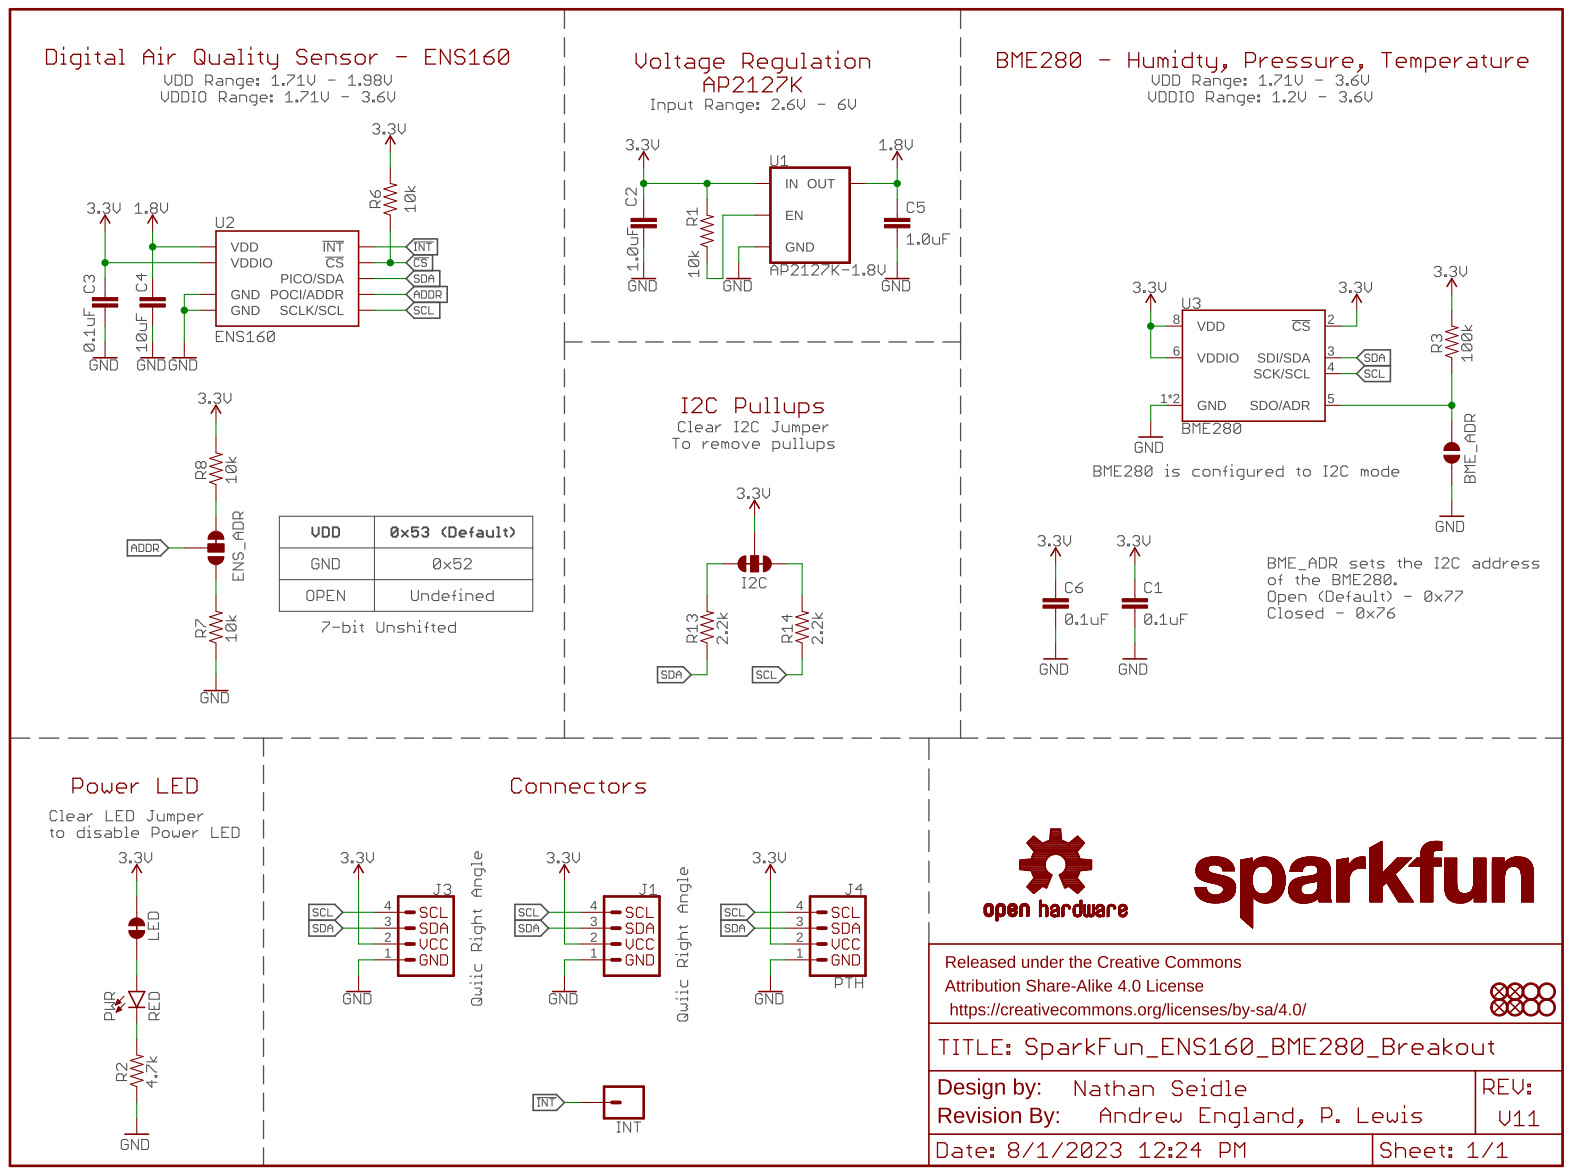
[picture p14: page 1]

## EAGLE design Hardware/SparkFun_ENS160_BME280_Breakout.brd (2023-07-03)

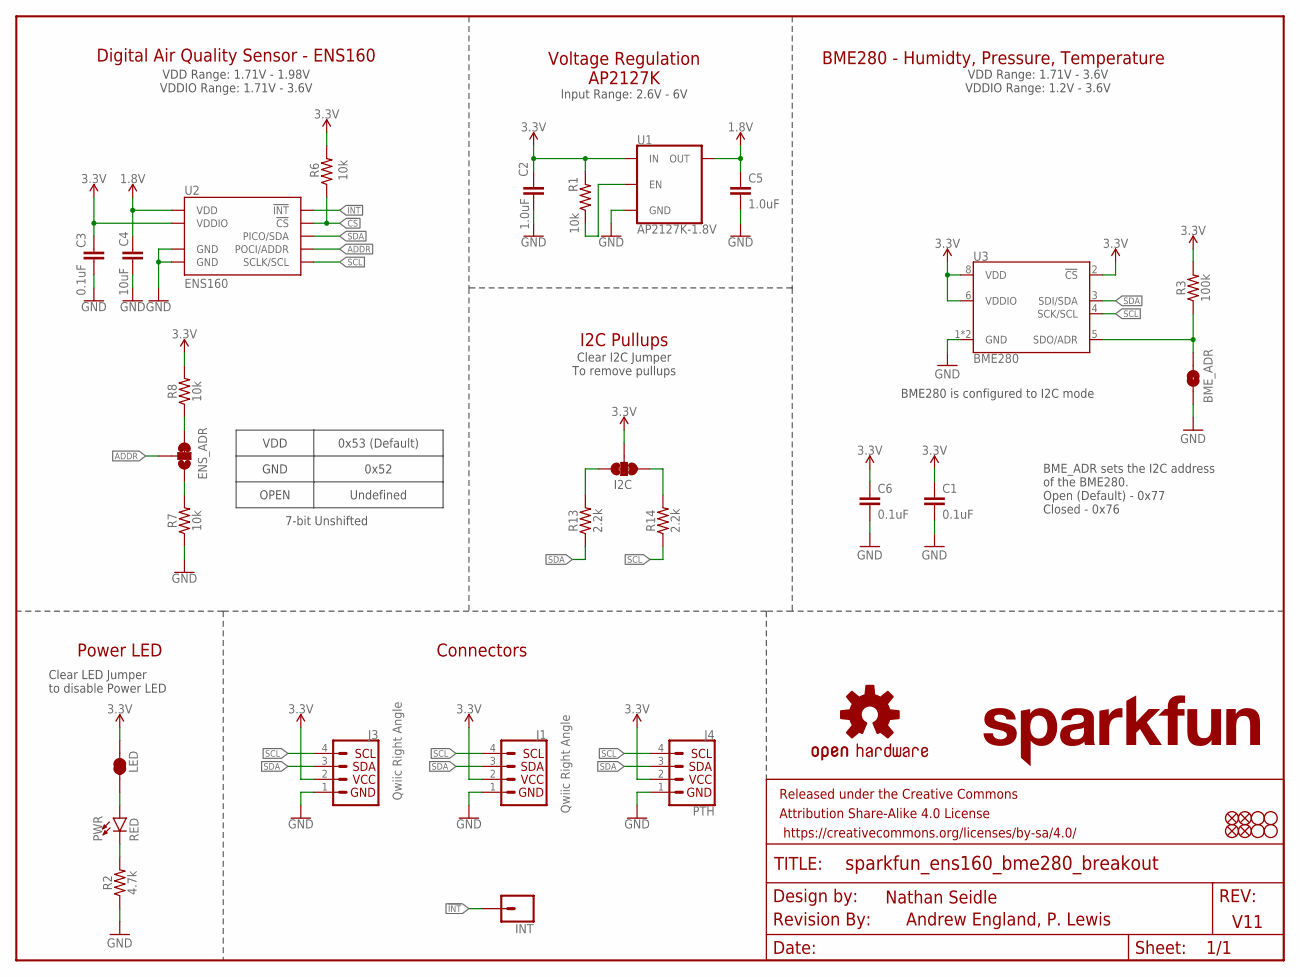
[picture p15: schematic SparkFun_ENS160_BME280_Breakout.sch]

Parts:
BME_ADR: JUMPER-SMT_2_NO_SILK; SMT-JUMPER_2_NO_SILK
C1, C3, C6: 0.1uF; 0402-TIGHT
C2, C5: 1.0uF; 0402-TIGHT
C4: 10uF; 0402-TIGHT
ENS_ADR: JUMPER-SMT_3_1-NC_TRACE_SILK; SMT-JUMPER_3_1-NC_TRACE_SILK
FD1, FD2, FD3, FD4: FIDUCIAL1X2; FIDUCIAL-1X2
FRAME1: FRAME-LETTER; CREATIVE_COMMONS
H1, H2, H3, H4: STAND-OFF
I2C: JUMPER-SMT_3_2-NC_TRACE_SILK; SMT-JUMPER_3_2-NC_TRACE_SILK
INT: CONN_01PTH_NO_SILK_STAND; 1X01_NO_SILK_STAND
J1, J3: Qwiic Right Angle; JST04_1MM_RA
J4: PTH; 1X04_NO_SILK
LED: JUMPER-SMT_2_NC_TRACE_SILK; SMT-JUMPER_2_NC_TRACE_SILK
LOGO1: SFE_LOGO_NAME.1_INCH; SFE_LOGO_NAME_.1
LOGO2: REVISION
LOGO4: OSHW-LOGOS; OSHW-LOGO-S
PWR: RED; LED-0603
R1, R6, R7, R8: 10k; 0402-TIGHT
R2: 4.7k; 0402-TIGHT
R3: 100k; 0402-TIGHT
R13, R14: 2.2k; 0402-TIGHT
U1: AP2127K-1.8V; SOT23-5
U2: ENS160; LGA-9
U3: BME280; LGA-8-2.5X2.5

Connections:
1.8V: C4.1, C5.1, U1.5 (OUT), U2.P4 (VDD)
3.3V: C1.1, C2.1, C3.1, C6.1, I2C.2, J1.2, J3.2, J4.2, LED.1, R1.2, R3.2, R6.2, R8.2, U1.1 (IN), U2.P5 (VDDIO), U3.2 (!CS), U3.6 (VDDIO), U3.8 (VDD)
!CS!: R6.1, U2.P7 (!CS!)
!INT!: INT.1, U2.P6 (!INT!)
ADDR: ENS_ADR.2, U2.P3 (POCI/ADDR)
GND: BME_ADR.1, C1.2, C2.2, C3.2, C4.2, C5.2, C6.2, J1.1, J3.1, J4.1, R2.1, R7.1, U1.2 (GND), U2.P8 (GND), U2.P9 (GND), U3.1 (GND), U3.7 (GND)
unnamed: ENS_ADR.3, R8.1
unnamed: R1.1, U1.3 (EN)
unnamed: I2C.3, R13.2
unnamed: I2C.1, R14.2
unnamed: PWR.C, R2.2
unnamed: ENS_ADR.1, R7.2
unnamed: LED.2, PWR.A
SCL: J1.4, J3.4, J4.4, R14.1, U2.P2 (SCLK/SCL), U3.4 (SCK/SCL)
SDA: J1.3, J3.3, J4.3, R13.1, U2.P1 (PICO/SDA), U3.3 (SDI/SDA)
SDO/ADR: BME_ADR.2, R3.1, U3.5 (SDO/ADR)

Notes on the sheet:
Clear I2C Jumper To remove pullups
V11
Nathan Seidle
BME_ADR sets the I2C address of the BME280. Open (Default) - 0x77 Closed - 0x76
BME280 is configured to I2C mode
BME280 - Humidty, Pressure, Temperature
Andrew England, P. Lewis
Digital Air Quality Sensor - ENS160
VDD Range: 1.71V - 1.98V VDDIO Range: 1.71V - 3.6V
VDD
GND
OPEN
0x52
0x53 (Default)
Undefined
7-bit Unshifted
Voltage Regulation AP2127K
Input Range: 2.6V - 6V
Clear LED Jumper to disable Power LED
Power LED
I2C Pullups
Connectors
VDD Range: 1.71V - 3.6V VDDIO Range: 1.2V - 3.6V

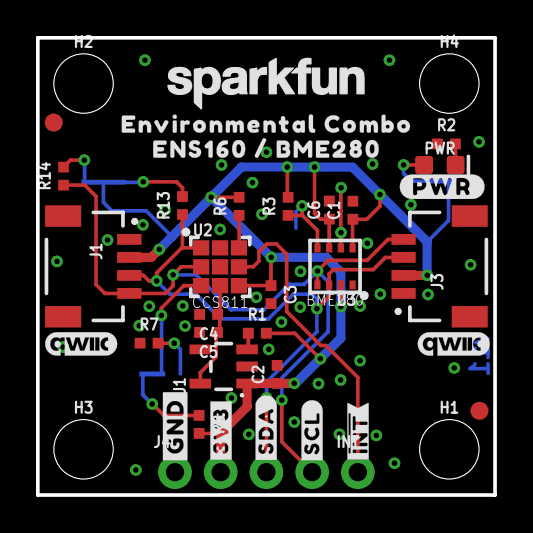
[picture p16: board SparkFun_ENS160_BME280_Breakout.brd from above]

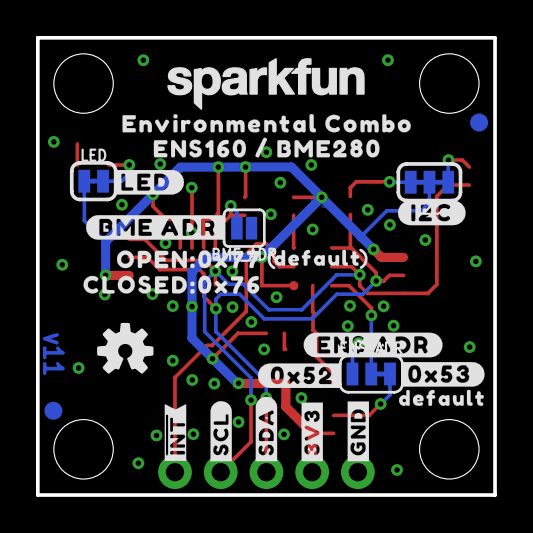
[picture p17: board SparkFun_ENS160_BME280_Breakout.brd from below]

Board: 2 copper layers, 25.4 x 25.4 mm, 67 parts (25 on the bottom side), 16 nets.

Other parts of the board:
LOGO3: SFE_LOGO_NAME.1_INCH; SFE_LOGO_NAME_.1@1
U$1: #BME_ADR#0
U$2: #0X53#0
U$3: #0X52#0
U$4: ##INT##6
U$5: #ENS_ADR#0
U$6: #I2C#0
U$7, U$11: ENVIRONMENTAL_COMBO0
U$8: #SCL#4
U$9: #GND#2
U$10, U$12: ENS160_#_BME2800
U$13, U$61: DEFAULT0
U$14: #SDA#3
U$15: #PWR#0
U$16: OPEN#0X770
U$17: CLOSED#0X760
U$18: #LED#0
U$20, U$21: QWIIC_4MM
U$27, U$46: #3V3#874
U$45: #GND#864
U$47: #SDA#874
U$48: #SCL#875
U$51: ##INT##877
U$59: ORDERING_INSTRUCTIONS

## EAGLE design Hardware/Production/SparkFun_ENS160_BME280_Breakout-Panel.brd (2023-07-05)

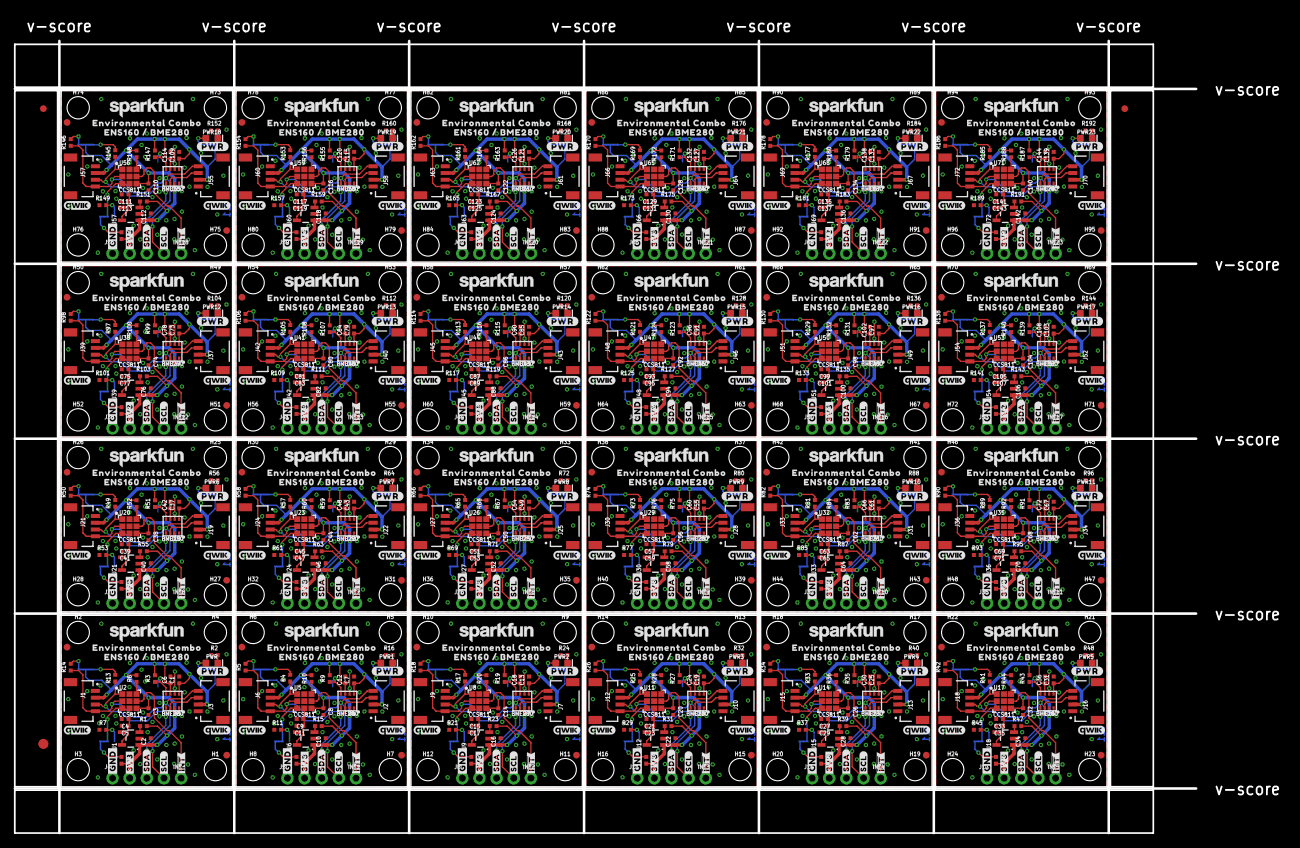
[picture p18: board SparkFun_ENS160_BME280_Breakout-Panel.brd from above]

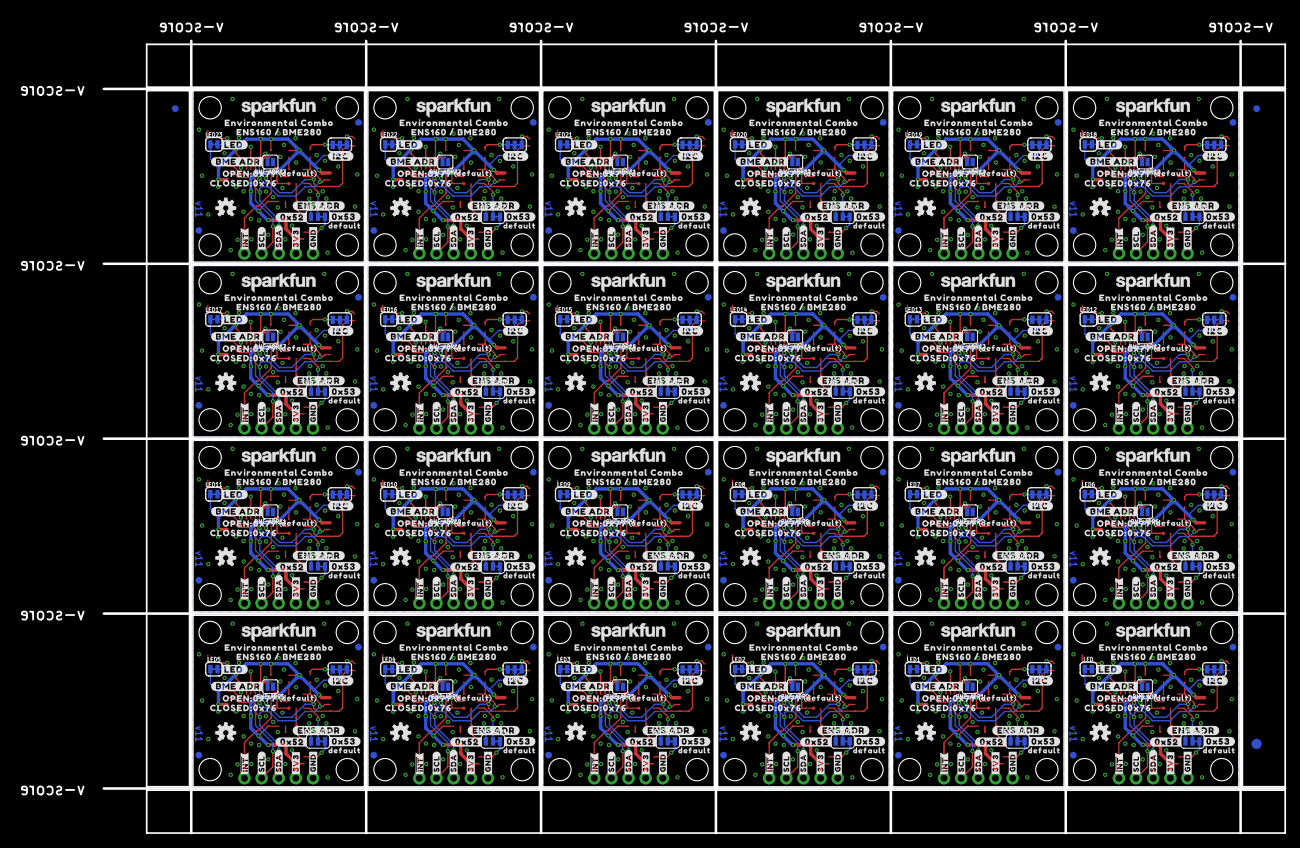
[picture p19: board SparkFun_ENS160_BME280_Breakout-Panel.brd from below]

Board: 2 copper layers, 175.0 x 117.3 mm, 1566 parts (603 on the bottom side), 384 nets.

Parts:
BME_ADR, BME_ADR1, BME_ADR2, BME_ADR3, BME_ADR4, BME_ADR5, BME_ADR6, BME_ADR7, BME_ADR8, BME_ADR9, BME_ADR10, BME_ADR11, BME_ADR12, BME_ADR13, BME_ADR14, BME_ADR15, BME_ADR16, BME_ADR17, BME_ADR18, BME_ADR19, BME_ADR20, BME_ADR21, BME_ADR22, BME_ADR23: SMT-JUMPER_2_NO_SILK
C1, C3, C6, C7, C8, C12, C13, C14, C18, C19, C20, C24, C25, C26, C30, C31, C32, C36, C37, C38, C42, C43, C44, C48, C49, C50, C54, C55, C56, C60, C61, C62, C66, C67, C68, C72, C73, C74, C78, C79, C80, C84, C85, C86, C90, C91, C92, C96, C97, C98, C102, C103, C104, C108, C109, C110, C114, C115, C116, C120, C121, C122, C126, C127, C128, C132, C133, C134, C138, C139, C140, C144: 0.1uF; 0402-TIGHT
C2, C5, C10, C11, C16, C17, C22, C23, C28, C29, C34, C35, C40, C41, C46, C47, C52, C53, C58, C59, C64, C65, C70, C71, C76, C77, C82, C83, C88, C89, C94, C95, C100, C101, C106, C107, C112, C113, C118, C119, C124, C125, C130, C131, C136, C137, C142, C143: 1.0uF; 0402-TIGHT
C4, C9, C15, C21, C27, C33, C39, C45, C51, C57, C63, C69, C75, C81, C87, C93, C99, C105, C111, C117, C123, C129, C135, C141: 10uF; 0402-TIGHT
E$1, E$2, E$3, E$4: FIDUCIAL-1X2
E$5, E$6: FIDUCIAL-1.5X3
ENS_ADR, ENS_ADR1, ENS_ADR2, ENS_ADR3, ENS_ADR4, ENS_ADR5, ENS_ADR6, ENS_ADR7, ENS_ADR8, ENS_ADR9, ENS_ADR10, ENS_ADR11, ENS_ADR12, ENS_ADR13, ENS_ADR14, ENS_ADR15, ENS_ADR16, ENS_ADR17, ENS_ADR18, ENS_ADR19, ENS_ADR20, ENS_ADR21, ENS_ADR22, ENS_ADR23: JUMPER-SMT_3_1-NC_TRACE_SILK; SMT-JUMPER_3_1-NC_TRACE_SILK
FD1, FD2, FD3, FD4, FD5, FD6, FD7, FD8, FD9, FD10, FD11, FD12, FD13, FD14, FD15, FD16, FD17, FD18, FD19, FD20, FD21, FD22, FD23, FD24, FD25, FD26, FD27, FD28, FD29, FD30, FD31, FD32, FD33, FD34, FD35, FD36, FD37, FD38, FD39, FD40, FD41, FD42, FD43, FD44, FD45, FD46, FD47, FD48, FD49, FD50, FD51, FD52, FD53, FD54, FD55, FD56, FD57, FD58, FD59, FD60, FD61, FD62, FD63, FD64, FD65, FD66, FD67, FD68, FD69, FD70, FD71, FD72, FD73, FD74, FD75, FD76, FD77, FD78, FD79, FD80, FD81, FD82, FD83, FD84, FD85, FD86, FD87, FD88, FD89, FD90, FD91, FD92, FD93, FD94, FD95, FD96: FIDUCIAL1X2; FIDUCIAL-1X2
H1, H2, H3, H4, H5, H6, H7, H8, H9, H10, H11, H12, H13, H14, H15, H16, H17, H18, H19, H20, H21, H22, H23, H24, H25, H26, H27, H28, H29, H30, H31, H32, H33, H34, H35, H36, H37, H38, H39, H40, H41, H42, H43, H44, H45, H46, H47, H48, H49, H50, H51, H52, H53, H54, H55, H56, H57, H58, H59, H60, H61, H62, H63, H64, H65, H66, H67, H68, H69, H70, H71, H72, H73, H74, H75, H76, H77, H78, H79, H80, H81, H82, H83, H84, H85, H86, H87, H88, H89, H90, H91, H92, H93, H94, H95, H96: STAND-OFF
I2C, I2C1, I2C2, I2C3, I2C4, I2C5, I2C6, I2C7, I2C8, I2C9, I2C10, I2C11, I2C12, I2C13, I2C14, I2C15, I2C16, I2C17, I2C18, I2C19, I2C20, I2C21, I2C22, I2C23: SMT-JUMPER_3_2-NC_TRACE_SILK
INT, INT1, INT2, INT3, INT4, INT5, INT6, INT7, INT8, INT9, INT10, INT11, INT12, INT13, INT14, INT15, INT16, INT17, INT18, INT19, INT20, INT21, INT22, INT23: 1X01_NO_SILK_STAND
J1, J2, J3, J6, J7, J9, J10, J12, J13, J15, J16, J18, J19, J21, J22, J24, J25, J27, J28, J30, J31, J33, J34, J36, J37, J39, J40, J42, J43, J45, J46, J48, J49, J51, J52, J54, J55, J57, J58, J60, J61, J63, J64, J66, J67, J69, J70, J72: Qwiic Right Angle; JST04_1MM_RA
J4, J5, J8, J11, J14, J17, J20, J23, J26, J29, J32, J35, J38, J41, J44, J47, J50, J53, J56, J59, J62, J65, J68, J71: PTH; 1X04_NO_SILK
LED, LED1, LED2, LED3, LED4, LED5, LED6, LED7, LED8, LED9, LED10, LED11, LED12, LED13, LED14, LED15, LED16, LED17, LED18, LED19, LED20, LED21, LED22, LED23: SMT-JUMPER_2_NC_TRACE_SILK
LOGO1, LOGO7, LOGO11, LOGO15, LOGO19, LOGO23, LOGO27, LOGO31, LOGO35, LOGO39, LOGO43, LOGO47, LOGO51, LOGO55, LOGO59, LOGO63, LOGO67, LOGO71, LOGO75, LOGO79, LOGO83, LOGO87, LOGO91, LOGO95: SFE_LOGO_NAME.1_INCH; SFE_LOGO_NAME_.1
LOGO2, LOGO6, LOGO10, LOGO14, LOGO18, LOGO22, LOGO26, LOGO30, LOGO34, LOGO38, LOGO42, LOGO46, LOGO50, LOGO54, LOGO58, LOGO62, LOGO66, LOGO70, LOGO74, LOGO78, LOGO82, LOGO86, LOGO90, LOGO94: REVISION
LOGO3, LOGO8, LOGO12, LOGO16, LOGO20, LOGO24, LOGO28, LOGO32, LOGO36, LOGO40, LOGO44, LOGO48, LOGO52, LOGO56, LOGO60, LOGO64, LOGO68, LOGO72, LOGO76, LOGO80, LOGO84, LOGO88, LOGO92, LOGO96: SFE_LOGO_NAME.1_INCH; SFE_LOGO_NAME_.1@1
LOGO4, LOGO5, LOGO9, LOGO13, LOGO17, LOGO21, LOGO25, LOGO29, LOGO33, LOGO37, LOGO41, LOGO45, LOGO49, LOGO53, LOGO57, LOGO61, LOGO65, LOGO69, LOGO73, LOGO77, LOGO81, LOGO85, LOGO89, LOGO93: OSHW-LOGOS; OSHW-LOGO-S
PWR, PWR1, PWR2, PWR3, PWR4, PWR5, PWR6, PWR7, PWR8, PWR9, PWR10, PWR11, PWR12, PWR13, PWR14, PWR15, PWR16, PWR17, PWR18, PWR19, PWR20, PWR21, PWR22, PWR23: RED; LED-0603
R1, R6, R7, R8, R10, R11, R12, R15, R20, R21, R22, R23, R28, R29, R30, R31, R36, R37, R38, R39, R44, R45, R46, R47, R52, R53, R54, R55, R60, R61, R62, R63, R68, R69, R70, R71, R76, R77, R78, R79, R84, R85, R86, R87, R92, R93, R94, R95, R100, R101, R102, R103, R108, R109, R110, R111, R116, R117, R118, R119, R124, R125, R126, R127, R132, R133, R134, R135, R140, R141, R142, R143, R148, R149, R150, R151, R156, R157, R158, R159, R164, R165, R166, R167, R172, R173, R174, R175, R180, R181, R182, R183, R188, R189, R190, R191: 10k; 0402-TIGHT
R2, R16, R24, R32, R40, R48, R56, R64, R72, R80, R88, R96, R104, R112, R120, R128, R136, R144, R152, R160, R168, R176, R184, R192: 4.7k; 0402-TIGHT
R3, R9, R19, R27, R35, R43, R51, R59, R67, R75, R83, R91, R99, R107, R115, R123, R131, R139, R147, R155, R163, R171, R179, R187: 100k; 0402-TIGHT
R4, R5, R13, R14, R17, R18, R25, R26, R33, R34, R41, R42, R49, R50, R57, R58, R65, R66, R73, R74, R81, R82, R89, R90, R97, R98, R105, R106, R113, R114, R121, R122, R129, R130, R137, R138, R145, R146, R153, R154, R161, R162, R169, R170, R177, R178, R185, R186: 2.2k; 0402-TIGHT
U1, U6, U9, U12, U15, U18, U21, U24, U27, U30, U33, U36, U39, U42, U45, U48, U51, U54, U57, U60, U63, U66, U69, U72: AP2127K-1.8V; SOT23-5
U2, U5, U8, U11, U14, U17, U20, U23, U26, U29, U32, U35, U38, U41, U44, U47, U50, U53, U56, U59, U62, U65, U68, U71: ENS160; LGA-9
U3, U4, U7, U10, U13, U16, U19, U22, U25, U28, U31, U34, U37, U40, U43, U46, U49, U52, U55, U58, U61, U64, U67, U70: BME280; LGA-8-2.5X2.5
U$1, U$41, U$74, U$101, U$128, U$155, U$182, U$209, U$236, U$263, U$290, U$317, U$344, U$371, U$398, U$425, U$452, U$479, U$506, U$533, U$560, U$587, U$614, U$641: #BME_ADR#0
U$2, U$32, U$65, U$92, U$119, U$146, U$173, U$200, U$227, U$254, U$281, U$308, U$335, U$362, U$389, U$416, U$443, U$470, U$497, U$524, U$551, U$578, U$605, U$632: #0X53#0
U$3, U$33, U$66, U$93, U$120, U$147, U$174, U$201, U$228, U$255, U$282, U$309, U$336, U$363, U$390, U$417, U$444, U$471, U$498, U$525, U$552, U$579, U$606, U$633: #0X52#0
U$4, U$31, U$64, U$91, U$118, U$145, U$172, U$199, U$226, U$253, U$280, U$307, U$334, U$361, U$388, U$415, U$442, U$469, U$496, U$523, U$550, U$577, U$604, U$631: ##INT##6
U$5, U$42, U$75, U$102, U$129, U$156, U$183, U$210, U$237, U$264, U$291, U$318, U$345, U$372, U$399, U$426, U$453, U$480, U$507, U$534, U$561, U$588, U$615, U$642: #ENS_ADR#0
U$6, U$34, U$67, U$94, U$121, U$148, U$175, U$202, U$229, U$256, U$283, U$310, U$337, U$364, U$391, U$418, U$445, U$472, U$499, U$526, U$553, U$580, U$607, U$634: #I2C#0
U$7, U$11, U$35, U$37, U$68, U$70, U$95, U$97, U$122, U$124, U$149, U$151, U$176, U$178, U$203, U$205, U$230, U$232, U$257, U$259, U$284, U$286, U$311, U$313, U$338, U$340, U$365, U$367, U$392, U$394, U$419, U$421, U$446, U$448, U$473, U$475, U$500, U$502, U$527, U$529, U$554, U$556, U$581, U$583, U$608, U$610, U$635, U$637: ENVIRONMENTAL_COMBO0
U$8, U$30, U$63, U$90, U$117, U$144, U$171, U$198, U$225, U$252, U$279, U$306, U$333, U$360, U$387, U$414, U$441, U$468, U$495, U$522, U$549, U$576, U$603, U$630: #SCL#4
U$9, U$28, U$60, U$88, U$115, U$142, U$169, U$196, U$223, U$250, U$277, U$304, U$331, U$358, U$385, U$412, U$439, U$466, U$493, U$520, U$547, U$574, U$601, U$628: #GND#2
U$10, U$12, U$36, U$38, U$69, U$71, U$96, U$98, U$123, U$125, U$150, U$152, U$177, U$179, U$204, U$206, U$231, U$233, U$258, U$260, U$285, U$287, U$312, U$314, U$339, U$341, U$366, U$368, U$393, U$395, U$420, U$422, U$447, U$449, U$474, U$476, U$501, U$503, U$528, U$530, U$555, U$557, U$582, U$584, U$609, U$611, U$636, U$638: ENS160_#_BME2800
U$13, U$43, U$44, U$61, U$76, U$77, U$103, U$104, U$130, U$131, U$157, U$158, U$184, U$185, U$211, U$212, U$238, U$239, U$265, U$266, U$292, U$293, U$319, U$320, U$346, U$347, U$373, U$374, U$400, U$401, U$427, U$428, U$454, U$455, U$481, U$482, U$508, U$509, U$535, U$536, U$562, U$563, U$589, U$590, U$616, U$617, U$643, U$644: DEFAULT0
U$14, U$29, U$62, U$89, U$116, U$143, U$170, U$197, U$224, U$251, U$278, U$305, U$332, U$359, U$386, U$413, U$440, U$467, U$494, U$521, U$548, U$575, U$602, U$629: #SDA#3
U$15, U$49, U$78, U$105, U$132, U$159, U$186, U$213, U$240, U$267, U$294, U$321, U$348, U$375, U$402, U$429, U$456, U$483, U$510, U$537, U$564, U$591, U$618, U$645: #PWR#0
U$16, U$39, U$72, U$99, U$126, U$153, U$180, U$207, U$234, U$261, U$288, U$315, U$342, U$369, U$396, U$423, U$450, U$477, U$504, U$531, U$558, U$585, U$612, U$639: OPEN#0X770
U$17, U$40, U$73, U$100, U$127, U$154, U$181, U$208, U$235, U$262, U$289, U$316, U$343, U$370, U$397, U$424, U$451, U$478, U$505, U$532, U$559, U$586, U$613, U$640: CLOSED#0X760
U$18, U$50, U$79, U$106, U$133, U$160, U$187, U$214, U$241, U$268, U$295, U$322, U$349, U$376, U$403, U$430, U$457, U$484, U$511, U$538, U$565, U$592, U$619, U$646: #LED#0
U$19, U$45, U$54, U$82, U$109, U$136, U$163, U$190, U$217, U$244, U$271, U$298, U$325, U$352, U$379, U$406, U$433, U$460, U$487, U$514, U$541, U$568, U$595, U$622: #GND#864
U$20, U$21, U$52, U$53, U$80, U$81, U$107, U$108, U$134, U$135, U$161, U$162, U$188, U$189, U$215, U$216, U$242, U$243, U$269, U$270, U$296, U$297, U$323, U$324, U$350, U$351, U$377, U$378, U$404, U$405, U$431, U$432, U$458, U$459, U$485, U$486, U$512, U$513, U$539, U$540, U$566, U$567, U$593, U$594, U$620, U$621, U$647, U$648: QWIIC_4MM
U$22, U$26, U$27, U$46, U$55, U$59, U$83, U$87, U$110, U$114, U$137, U$141, U$164, U$168, U$191, U$195, U$218, U$222, U$245, U$249, U$272, U$276, U$299, U$303, U$326, U$330, U$353, U$357, U$380, U$384, U$407, U$411, U$434, U$438, U$461, U$465, U$488, U$492, U$515, U$519, U$542, U$546, U$569, U$573, U$596, U$600, U$623, U$627: #3V3#874
U$23, U$47, U$56, U$84, U$111, U$138, U$165, U$192, U$219, U$246, U$273, U$300, U$327, U$354, U$381, U$408, U$435, U$462, U$489, U$516, U$543, U$570, U$597, U$624: #SDA#874
U$24, U$48, U$57, U$85, U$112, U$139, U$166, U$193, U$220, U$247, U$274, U$301, U$328, U$355, U$382, U$409, U$436, U$463, U$490, U$517, U$544, U$571, U$598, U$625: #SCL#875
U$25, U$51, U$58, U$86, U$113, U$140, U$167, U$194, U$221, U$248, U$275, U$302, U$329, U$356, U$383, U$410, U$437, U$464, U$491, U$518, U$545, U$572, U$599, U$626: ##INT##877

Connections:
1.8V: C4.1, C5.1, U1.5, U2.P4
1.8V1: C9.1, C11.1, U5.P4, U6.5
1.8V2: C15.1, C17.1, U8.P4, U9.5
1.8V3: C21.1, C23.1, U11.P4, U12.5
1.8V4: C27.1, C29.1, U14.P4, U15.5
1.8V5: C33.1, C35.1, U17.P4, U18.5
1.8V6: C39.1, C41.1, U20.P4, U21.5
1.8V7: C45.1, C47.1, U23.P4, U24.5
1.8V8: C51.1, C53.1, U26.P4, U27.5
1.8V9: C57.1, C59.1, U29.P4, U30.5
1.8V10: C63.1, C65.1, U32.P4, U33.5
1.8V11: C69.1, C71.1, U35.P4, U36.5
1.8V12: C75.1, C77.1, U38.P4, U39.5
1.8V13: C81.1, C83.1, U41.P4, U42.5
1.8V14: C87.1, C89.1, U44.P4, U45.5
1.8V15: C93.1, C95.1, U47.P4, U48.5
1.8V16: C99.1, C101.1, U50.P4, U51.5
1.8V17: C105.1, C107.1, U53.P4, U54.5
1.8V18: C111.1, C113.1, U56.P4, U57.5
1.8V19: C117.1, C119.1, U59.P4, U60.5
1.8V20: C123.1, C125.1, U62.P4, U63.5
1.8V21: C129.1, C131.1, U65.P4, U66.5
1.8V22: C135.1, C137.1, U68.P4, U69.5
1.8V23: C141.1, C143.1, U71.P4, U72.5
3.3V: C1.1, C2.1, C3.1, C6.1, I2C.2, J1.2, J3.2, J4.2, LED.1, R1.2, R3.2, R6.2, R8.2, U1.1, U2.P5, U3.2, U3.6, U3.8
3.3V1: C7.1, C8.1, C10.1, C12.1, I2C1.2, J2.2, J5.2, J6.2, LED1.1, R9.2, R10.2, R12.2, R15.2, U4.2, U4.6, U4.8, U5.P5, U6.1
3.3V2: C13.1, C14.1, C16.1, C18.1, I2C2.2, J7.2, J8.2, J9.2, LED2.1, R19.2, R20.2, R22.2, R23.2, U7.2, U7.6, U7.8, U8.P5, U9.1
3.3V3: C19.1, C20.1, C22.1, C24.1, I2C3.2, J10.2, J11.2, J12.2, LED3.1, R27.2, R28.2, R30.2, R31.2, U10.2, U10.6, U10.8, U11.P5, U12.1
3.3V4: C25.1, C26.1, C28.1, C30.1, I2C4.2, J13.2, J14.2, J15.2, LED4.1, R35.2, R36.2, R38.2, R39.2, U13.2, U13.6, U13.8, U14.P5, U15.1
3.3V5: C31.1, C32.1, C34.1, C36.1, I2C5.2, J16.2, J17.2, J18.2, LED5.1, R43.2, R44.2, R46.2, R47.2, U16.2, U16.6, U16.8, U17.P5, U18.1
3.3V6: C37.1, C38.1, C40.1, C42.1, I2C6.2, J19.2, J20.2, J21.2, LED6.1, R51.2, R52.2, R54.2, R55.2, U19.2, U19.6, U19.8, U20.P5, U21.1
3.3V7: C43.1, C44.1, C46.1, C48.1, I2C7.2, J22.2, J23.2, J24.2, LED7.1, R59.2, R60.2, R62.2, R63.2, U22.2, U22.6, U22.8, U23.P5, U24.1
3.3V8: C49.1, C50.1, C52.1, C54.1, I2C8.2, J25.2, J26.2, J27.2, LED8.1, R67.2, R68.2, R70.2, R71.2, U25.2, U25.6, U25.8, U26.P5, U27.1
3.3V9: C55.1, C56.1, C58.1, C60.1, I2C9.2, J28.2, J29.2, J30.2, LED9.1, R75.2, R76.2, R78.2, R79.2, U28.2, U28.6, U28.8, U29.P5, U30.1
3.3V10: C61.1, C62.1, C64.1, C66.1, I2C10.2, J31.2, J32.2, J33.2, LED10.1, R83.2, R84.2, R86.2, R87.2, U31.2, U31.6, U31.8, U32.P5, U33.1
3.3V11: C67.1, C68.1, C70.1, C72.1, I2C11.2, J34.2, J35.2, J36.2, LED11.1, R91.2, R92.2, R94.2, R95.2, U34.2, U34.6, U34.8, U35.P5, U36.1
3.3V12: C73.1, C74.1, C76.1, C78.1, I2C12.2, J37.2, J38.2, J39.2, LED12.1, R99.2, R100.2, R102.2, R103.2, U37.2, U37.6, U37.8, U38.P5, U39.1
3.3V13: C79.1, C80.1, C82.1, C84.1, I2C13.2, J40.2, J41.2, J42.2, LED13.1, R107.2, R108.2, R110.2, R111.2, U40.2, U40.6, U40.8, U41.P5, U42.1
3.3V14: C85.1, C86.1, C88.1, C90.1, I2C14.2, J43.2, J44.2, J45.2, LED14.1, R115.2, R116.2, R118.2, R119.2, U43.2, U43.6, U43.8, U44.P5, U45.1
3.3V15: C91.1, C92.1, C94.1, C96.1, I2C15.2, J46.2, J47.2, J48.2, LED15.1, R123.2, R124.2, R126.2, R127.2, U46.2, U46.6, U46.8, U47.P5, U48.1
3.3V16: C97.1, C98.1, C100.1, C102.1, I2C16.2, J49.2, J50.2, J51.2, LED16.1, R131.2, R132.2, R134.2, R135.2, U49.2, U49.6, U49.8, U50.P5, U51.1
3.3V17: C103.1, C104.1, C106.1, C108.1, I2C17.2, J52.2, J53.2, J54.2, LED17.1, R139.2, R140.2, R142.2, R143.2, U52.2, U52.6, U52.8, U53.P5, U54.1
3.3V18: C109.1, C110.1, C112.1, C114.1, I2C18.2, J55.2, J56.2, J57.2, LED18.1, R147.2, R148.2, R150.2, R151.2, U55.2, U55.6, U55.8, U56.P5, U57.1
3.3V19: C115.1, C116.1, C118.1, C120.1, I2C19.2, J58.2, J59.2, J60.2, LED19.1, R155.2, R156.2, R158.2, R159.2, U58.2, U58.6, U58.8, U59.P5, U60.1
3.3V20: C121.1, C122.1, C124.1, C126.1, I2C20.2, J61.2, J62.2, J63.2, LED20.1, R163.2, R164.2, R166.2, R167.2, U61.2, U61.6, U61.8, U62.P5, U63.1
3.3V21: C127.1, C128.1, C130.1, C132.1, I2C21.2, J64.2, J65.2, J66.2, LED21.1, R171.2, R172.2, R174.2, R175.2, U64.2, U64.6, U64.8, U65.P5, U66.1
3.3V22: C133.1, C134.1, C136.1, C138.1, I2C22.2, J67.2, J68.2, J69.2, LED22.1, R179.2, R180.2, R182.2, R183.2, U67.2, U67.6, U67.8, U68.P5, U69.1
3.3V23: C139.1, C140.1, C142.1, C144.1, I2C23.2, J70.2, J71.2, J72.2, LED23.1, R187.2, R188.2, R190.2, R191.2, U70.2, U70.6, U70.8, U71.P5, U72.1
!CS!: R6.1, U2.P7
!CS!1: R10.1, U5.P7
!CS!2: R20.1, U8.P7
!CS!3: R28.1, U11.P7
!CS!4: R36.1, U14.P7
!CS!5: R44.1, U17.P7
!CS!6: R52.1, U20.P7
!CS!7: R60.1, U23.P7
!CS!8: R68.1, U26.P7
!CS!9: R76.1, U29.P7
!CS!10: R84.1, U32.P7
!CS!11: R92.1, U35.P7
!CS!12: R100.1, U38.P7
!CS!13: R108.1, U41.P7
!CS!14: R116.1, U44.P7
!CS!15: R124.1, U47.P7
!CS!16: R132.1, U50.P7
!CS!17: R140.1, U53.P7
!CS!18: R148.1, U56.P7
!CS!19: R156.1, U59.P7
!CS!20: R164.1, U62.P7
!CS!21: R172.1, U65.P7
!CS!22: R180.1, U68.P7
!CS!23: R188.1, U71.P7
!INT!: INT.1, U2.P6
!INT!1: INT1.1, U5.P6
!INT!2: INT2.1, U8.P6
!INT!3: INT3.1, U11.P6
!INT!4: INT4.1, U14.P6
!INT!5: INT5.1, U17.P6
!INT!6: INT6.1, U20.P6
!INT!7: INT7.1, U23.P6
!INT!8: INT8.1, U26.P6
!INT!9: INT9.1, U29.P6
!INT!10: INT10.1, U32.P6
!INT!11: INT11.1, U35.P6
!INT!12: INT12.1, U38.P6
!INT!13: INT13.1, U41.P6
!INT!14: INT14.1, U44.P6
!INT!15: INT15.1, U47.P6
!INT!16: INT16.1, U50.P6
!INT!17: INT17.1, U53.P6
!INT!18: INT18.1, U56.P6
!INT!19: INT19.1, U59.P6
!INT!20: INT20.1, U62.P6
!INT!21: INT21.1, U65.P6
!INT!22: INT22.1, U68.P6
!INT!23: INT23.1, U71.P6
ADDR: ENS_ADR.2, U2.P3
ADDR1: ENS_ADR1.2, U5.P3
ADDR2: ENS_ADR2.2, U8.P3
ADDR3: ENS_ADR3.2, U11.P3
ADDR4: ENS_ADR4.2, U14.P3
ADDR5: ENS_ADR5.2, U17.P3
ADDR6: ENS_ADR6.2, U20.P3
ADDR7: ENS_ADR7.2, U23.P3
ADDR8: ENS_ADR8.2, U26.P3
ADDR9: ENS_ADR9.2, U29.P3
ADDR10: ENS_ADR10.2, U32.P3
ADDR11: ENS_ADR11.2, U35.P3
ADDR12: ENS_ADR12.2, U38.P3
ADDR13: ENS_ADR13.2, U41.P3
ADDR14: ENS_ADR14.2, U44.P3
ADDR15: ENS_ADR15.2, U47.P3
ADDR16: ENS_ADR16.2, U50.P3
ADDR17: ENS_ADR17.2, U53.P3
ADDR18: ENS_ADR18.2, U56.P3
ADDR19: ENS_ADR19.2, U59.P3
ADDR20: ENS_ADR20.2, U62.P3
ADDR21: ENS_ADR21.2, U65.P3
ADDR22: ENS_ADR22.2, U68.P3
ADDR23: ENS_ADR23.2, U71.P3
GND: BME_ADR.1, C1.2, C2.2, C3.2, C4.2, C5.2, C6.2, J1.1, J3.1, J4.1, R2.1, R7.1, U1.2, U2.P8, U2.P9, U3.1, U3.7
GND1: BME_ADR1.1, C7.2, C8.2, C9.2, C10.2, C11.2, C12.2, J2.1, J5.1, J6.1, R11.1, R16.1, U4.1, U4.7, U5.P8, U5.P9, U6.2
GND2: BME_ADR2.1, C13.2, C14.2, C15.2, C16.2, C17.2, C18.2, J7.1, J8.1, J9.1, R21.1, R24.1, U7.1, U7.7, U8.P8, U8.P9, U9.2
GND3: BME_ADR3.1, C19.2, C20.2, C21.2, C22.2, C23.2, C24.2, J10.1, J11.1, J12.1, R29.1, R32.1, U10.1, U10.7, U11.P8, U11.P9, U12.2
GND4: BME_ADR4.1, C25.2, C26.2, C27.2, C28.2, C29.2, C30.2, J13.1, J14.1, J15.1, R37.1, R40.1, U13.1, U13.7, U14.P8, U14.P9, U15.2
GND5: BME_ADR5.1, C31.2, C32.2, C33.2, C34.2, C35.2, C36.2, J16.1, J17.1, J18.1, R45.1, R48.1, U16.1, U16.7, U17.P8, U17.P9, U18.2
GND6: BME_ADR6.1, C37.2, C38.2, C39.2, C40.2, C41.2, C42.2, J19.1, J20.1, J21.1, R53.1, R56.1, U19.1, U19.7, U20.P8, U20.P9, U21.2
GND7: BME_ADR7.1, C43.2, C44.2, C45.2, C46.2, C47.2, C48.2, J22.1, J23.1, J24.1, R61.1, R64.1, U22.1, U22.7, U23.P8, U23.P9, U24.2
GND8: BME_ADR8.1, C49.2, C50.2, C51.2, C52.2, C53.2, C54.2, J25.1, J26.1, J27.1, R69.1, R72.1, U25.1, U25.7, U26.P8, U26.P9, U27.2
GND9: BME_ADR9.1, C55.2, C56.2, C57.2, C58.2, C59.2, C60.2, J28.1, J29.1, J30.1, R77.1, R80.1, U28.1, U28.7, U29.P8, U29.P9, U30.2
GND10: BME_ADR10.1, C61.2, C62.2, C63.2, C64.2, C65.2, C66.2, J31.1, J32.1, J33.1, R85.1, R88.1, U31.1, U31.7, U32.P8, U32.P9, U33.2
GND11: BME_ADR11.1, C67.2, C68.2, C69.2, C70.2, C71.2, C72.2, J34.1, J35.1, J36.1, R93.1, R96.1, U34.1, U34.7, U35.P8, U35.P9, U36.2
GND12: BME_ADR12.1, C73.2, C74.2, C75.2, C76.2, C77.2, C78.2, J37.1, J38.1, J39.1, R101.1, R104.1, U37.1, U37.7, U38.P8, U38.P9, U39.2
GND13: BME_ADR13.1, C79.2, C80.2, C81.2, C82.2, C83.2, C84.2, J40.1, J41.1, J42.1, R109.1, R112.1, U40.1, U40.7, U41.P8, U41.P9, U42.2
GND14: BME_ADR14.1, C85.2, C86.2, C87.2, C88.2, C89.2, C90.2, J43.1, J44.1, J45.1, R117.1, R120.1, U43.1, U43.7, U44.P8, U44.P9, U45.2
GND15: BME_ADR15.1, C91.2, C92.2, C93.2, C94.2, C95.2, C96.2, J46.1, J47.1, J48.1, R125.1, R128.1, U46.1, U46.7, U47.P8, U47.P9, U48.2
GND16: BME_ADR16.1, C97.2, C98.2, C99.2, C100.2, C101.2, C102.2, J49.1, J50.1, J51.1, R133.1, R136.1, U49.1, U49.7, U50.P8, U50.P9, U51.2
GND17: BME_ADR17.1, C103.2, C104.2, C105.2, C106.2, C107.2, C108.2, J52.1, J53.1, J54.1, R141.1, R144.1, U52.1, U52.7, U53.P8, U53.P9, U54.2
GND18: BME_ADR18.1, C109.2, C110.2, C111.2, C112.2, C113.2, C114.2, J55.1, J56.1, J57.1, R149.1, R152.1, U55.1, U55.7, U56.P8, U56.P9, U57.2
GND19: BME_ADR19.1, C115.2, C116.2, C117.2, C118.2, C119.2, C120.2, J58.1, J59.1, J60.1, R157.1, R160.1, U58.1, U58.7, U59.P8, U59.P9, U60.2
GND20: BME_ADR20.1, C121.2, C122.2, C123.2, C124.2, C125.2, C126.2, J61.1, J62.1, J63.1, R165.1, R168.1, U61.1, U61.7, U62.P8, U62.P9, U63.2
GND21: BME_ADR21.1, C127.2, C128.2, C129.2, C130.2, C131.2, C132.2, J64.1, J65.1, J66.1, R173.1, R176.1, U64.1, U64.7, U65.P8, U65.P9, U66.2
GND22: BME_ADR22.1, C133.2, C134.2, C135.2, C136.2, C137.2, C138.2, J67.1, J68.1, J69.1, R181.1, R184.1, U67.1, U67.7, U68.P8, U68.P9, U69.2
GND23: BME_ADR23.1, C139.2, C140.2, C141.2, C142.2, C143.2, C144.2, J70.1, J71.1, J72.1, R189.1, R192.1, U70.1, U70.7, U71.P8, U71.P9, U72.2
unnamed: I2C1.3, R4.2
unnamed: ENS_ADR.3, R8.1
unnamed: R1.1, U1.3
unnamed: I2C.3, R13.2
unnamed: I2C.1, R14.2
unnamed: PWR.C, R2.2
unnamed: ENS_ADR.1, R7.2
unnamed: LED.2, PWR.A
unnamed: I2C1.1, R5.2
unnamed: ENS_ADR1.3, R12.1
unnamed: ENS_ADR1.1, R11.2
unnamed: R15.1, U6.3
unnamed: PWR1.C, R16.2
unnamed: LED1.2, PWR1.A
unnamed: I2C2.3, R17.2
unnamed: I2C2.1, R18.2
unnamed: ENS_ADR2.3, R22.1
unnamed: ENS_ADR2.1, R21.2
unnamed: R23.1, U9.3
unnamed: PWR2.C, R24.2
unnamed: LED2.2, PWR2.A
unnamed: I2C3.3, R25.2
unnamed: I2C3.1, R26.2
unnamed: ENS_ADR3.3, R30.1
unnamed: ENS_ADR3.1, R29.2
unnamed: R31.1, U12.3
unnamed: PWR3.C, R32.2
unnamed: LED3.2, PWR3.A
unnamed: I2C4.3, R33.2
unnamed: I2C4.1, R34.2
unnamed: ENS_ADR4.3, R38.1
unnamed: ENS_ADR4.1, R37.2
unnamed: R39.1, U15.3
unnamed: PWR4.C, R40.2
unnamed: LED4.2, PWR4.A
unnamed: I2C5.3, R41.2
unnamed: I2C5.1, R42.2
unnamed: ENS_ADR5.3, R46.1
unnamed: ENS_ADR5.1, R45.2
unnamed: R47.1, U18.3
unnamed: PWR5.C, R48.2
unnamed: LED5.2, PWR5.A
unnamed: I2C6.3, R49.2
unnamed: I2C6.1, R50.2
unnamed: ENS_ADR6.3, R54.1
unnamed: ENS_ADR6.1, R53.2
unnamed: R55.1, U21.3
unnamed: PWR6.C, R56.2
unnamed: LED6.2, PWR6.A
unnamed: I2C7.3, R57.2
unnamed: I2C7.1, R58.2
unnamed: ENS_ADR7.3, R62.1
unnamed: ENS_ADR7.1, R61.2
unnamed: R63.1, U24.3
unnamed: PWR7.C, R64.2
unnamed: LED7.2, PWR7.A
unnamed: I2C8.3, R65.2
unnamed: I2C8.1, R66.2
unnamed: ENS_ADR8.3, R70.1
unnamed: ENS_ADR8.1, R69.2
unnamed: R71.1, U27.3
unnamed: PWR8.C, R72.2
unnamed: LED8.2, PWR8.A
unnamed: I2C9.3, R73.2
unnamed: I2C9.1, R74.2
unnamed: ENS_ADR9.3, R78.1
unnamed: ENS_ADR9.1, R77.2
unnamed: R79.1, U30.3
unnamed: PWR9.C, R80.2
unnamed: LED9.2, PWR9.A
unnamed: I2C10.3, R81.2
unnamed: I2C10.1, R82.2
unnamed: ENS_ADR10.3, R86.1
unnamed: ENS_ADR10.1, R85.2
unnamed: R87.1, U33.3
unnamed: PWR10.C, R88.2
unnamed: LED10.2, PWR10.A
unnamed: I2C11.3, R89.2
unnamed: I2C11.1, R90.2
unnamed: ENS_ADR11.3, R94.1
unnamed: ENS_ADR11.1, R93.2
unnamed: R95.1, U36.3
unnamed: PWR11.C, R96.2
unnamed: LED11.2, PWR11.A
unnamed: I2C12.3, R97.2
unnamed: I2C12.1, R98.2
unnamed: ENS_ADR12.3, R102.1
unnamed: ENS_ADR12.1, R101.2
unnamed: R103.1, U39.3
unnamed: PWR12.C, R104.2
unnamed: LED12.2, PWR12.A
unnamed: I2C13.3, R105.2
unnamed: I2C13.1, R106.2
unnamed: ENS_ADR13.3, R110.1
unnamed: ENS_ADR13.1, R109.2
unnamed: R111.1, U42.3
unnamed: PWR13.C, R112.2
unnamed: LED13.2, PWR13.A
unnamed: I2C14.3, R113.2
unnamed: I2C14.1, R114.2
unnamed: ENS_ADR14.3, R118.1
unnamed: ENS_ADR14.1, R117.2
unnamed: R119.1, U45.3
unnamed: PWR14.C, R120.2
unnamed: LED14.2, PWR14.A
unnamed: I2C15.3, R121.2
unnamed: I2C15.1, R122.2
unnamed: ENS_ADR15.3, R126.1
unnamed: ENS_ADR15.1, R125.2
unnamed: R127.1, U48.3
unnamed: PWR15.C, R128.2
unnamed: LED15.2, PWR15.A
unnamed: I2C16.3, R129.2
unnamed: I2C16.1, R130.2
unnamed: ENS_ADR16.3, R134.1
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

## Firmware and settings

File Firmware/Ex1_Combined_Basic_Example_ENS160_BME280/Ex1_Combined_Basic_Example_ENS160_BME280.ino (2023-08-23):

/* Ex1_Combined_Basic_Example_ENS160_BME280.ino

This example shows basic data retrieval from the SparkFun Environmental Combo Breakout
from the Air Quality Sensor (ENS160) and Atmospheric Sensor (BME280).

This example shows how to read sensor readings from the ENS160 (air quality index tVOC, and eCO2)
and BME280 (humidity, pressure, and current temperature) over I2C.

Modified by:
Ho Yun "Bobby" Chan @ SparkFun Electronics August, 2023
Basic Example for the ENS160 Originally Written by:
Elias Santistevan @ SparkFun Electronics October, 2022
Basic Example for the ENS160 Originally Written by:
Nathan Seidle @ SparkFun Electronics March 9th, 2018

Products:
Air Quality Sensor  (ENS160)             -  https://www.sparkfun.com/products/20844
Humidity and Temperature Sensor (BME280) -  https://www.sparkfun.com/products/13676

Repository:
https://github.com/sparkfun/SparkFun_Indoor_Air_Quality_Sensor-ENS160_Arduino_Library

SparkFun code, firmware, and software is released under the MIT
License(http://opensource.org/licenses/MIT).

*/
#define Serial SerialUSB  //Uncomment if you are using a native USB like the Atmega32U4 or SAMD21


#include <Wire.h>
#include "SparkFun_ENS160.h"  // Click here to get the library: http://librarymanager/All#SparkFun_ENS160
#include "SparkFunBME280.h"   // Click here to get the library: http://librarymanager/All#SparkFun_BME280

SparkFun_ENS160 myENS;
BME280 myBME280;

int ensStatus;

void setup() {
  Wire.begin();

  Serial.begin(115200);

  if (!myENS.begin()) {
    Serial.println("Did not begin.");
    while (1)
      ;
  }

  if (myBME280.beginI2C() == false)  //Begin communication over I2C
  {
    Serial.println("The sensor did not respond. Please check wiring.");
    while (1)
      ;  //Freeze
  }

  // Reset the indoor air quality sensor's settings.
  if (myENS.setOperatingMode(SFE_ENS160_RESET))
    Serial.println("Ready.");

  delay(100);

  // Device needs to be set to idle to apply any settings.
  // myENS.setOperatingMode(SFE_ENS160_IDLE);

  // Set to standard operation
  // Others include SFE_ENS160_DEEP_SLEEP and SFE_ENS160_IDLE
  myENS.setOperatingMode(SFE_ENS160_STANDARD);

  // There are four values here:
  // 0 - Operating ok: Standard Operation
  // 1 - Warm-up: occurs for 3 minutes after power-on.
  // 2 - Initial Start-up: Occurs for the first hour of operation.
  //                                              and only once in sensor's lifetime.
  // 3 - No Valid Output
  ensStatus = myENS.getFlags();
  Serial.print("Gas Sensor Status Flag: ");
  Serial.println(ensStatus);
}

void loop() {
  if (myENS.checkDataStatus()) {
    Serial.print("Air Quality Index (1-5) : ");
    Serial.println(myENS.getAQI());

    Serial.print("Total Volatile Organic Compounds: ");
    Serial.print(myENS.getTVOC());
    Serial.println("ppb");

    Serial.print("CO2 concentration: ");
    Serial.print(myENS.getECO2());
    Serial.println("ppm");

    Serial.print("Humidity: ");
    Serial.print(myBME280.readFloatHumidity(), 0);
    Serial.println("RH%");

    Serial.print("Pressure: ");
    Serial.print(myBME280.readFloatPressure(), 0);
    Serial.println("Pa");

    Serial.print("Alt: ");
    //Serial.print(myBME280.readFloatAltitudeMeters(), 1);
    //Serial.println("meters");
    Serial.print(myBME280.readFloatAltitudeFeet(), 1);
    Serial.println("feet");

    Serial.print("Temp: ");
    //Serial.print(myBME280.readTempC(), 2);
    //Serial.println(" degC");
    Serial.print(myBME280.readTempF(), 2);
    Serial.println(" degF");

    Serial.println();
  }



  delay(200);
}

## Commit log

2023-06-29 Layout almost done
    [SparkFun_ENS160_BME280_Breakout..sch, SparkFun_ENS160_BME280_Breakout.brd, SparkFun_ENS160_BME280_Breakout.sch]
2023-06-30 measures to inches and added more
    [SparkFun_ENS160_BME280_Breakout..sch, SparkFun_ENS160_BME280_Breakout.brd, SparkFun_ENS160_BME280_Breakout.sch]
2023-06-30 sch cleanup
    [SparkFun_ENS160_BME280_Breakout.sch]
2023-06-30 added a 100nF cap to VDDIO on BME280
    -added C6
    -re-routed 3V3 and GND for better return path to GND pads on ICs
    [SparkFun_ENS160_BME280_Breakout.brd, SparkFun_ENS160_BME280_Breakout.sch]
2023-06-30 soldermask color to red in manufacturing tab rendering
    [SparkFun_ENS160_BME280_Breakout.brd]
2023-07-03 group review changes - qwiic logos, via nudging
    -added Qwiic logos to top silk
    -nudged some filter caps near the ENS160 to allow even better GND flow
    -removed old "ADDR" silk object on bottom silk.
    [SparkFun_ENS160_BME280_Breakout.brd]
2023-07-03 checklist run eng
    -VCC ranges added for bME280
    -corrected BME_ADR jumper comment
    -moved ENS160 to SFE library
    [SparkFun_ENS160_BME280_Breakout.brd, SparkFun_ENS160_BME280_Breakout.sch]
2023-07-05 Production panel and gerbers v11
    [SparkFun_ENS160_BME280_Breakout-Panel.GBL, SparkFun_ENS160_BME280_Breakout-Panel.GBP, SparkFun_ENS160_BME280_Breakout-Panel.GBS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]
2023-08-22 Add Combined Arduino Examples
2023-11-14 Remove "Hide" from Style
    - Remove the "hide" from the style to ensure that the images/tutorials show up when printing

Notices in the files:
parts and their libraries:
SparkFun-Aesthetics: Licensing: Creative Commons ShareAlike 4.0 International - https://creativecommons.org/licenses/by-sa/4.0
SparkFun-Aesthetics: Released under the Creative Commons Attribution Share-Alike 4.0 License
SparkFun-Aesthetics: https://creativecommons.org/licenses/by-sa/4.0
